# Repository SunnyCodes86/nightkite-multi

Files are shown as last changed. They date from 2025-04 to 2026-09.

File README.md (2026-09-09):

# Lenkdrachen LED Beleuchtung mit Bewegungsreaktion (Kite LED Lighting with Motion Response)

## Deutsch *(Version 3.0)*

Dieses Projekt realisiert eine dynamische LED-Beleuchtung für Lenkdrachen, die auf deren Bewegungen und Beschleunigungen reagiert. Die Farbe der LEDs wird durch den aktuellen Winkel des Drachens bestimmt, während die Geschwindigkeit der Animationsabläufe von der Bewegungsgeschwindigkeit des Drachens abhängt.

[Bedienungsanleitung](manual/manual_de.md)

### Features

* Helligkeit in 6 Stufen (95 → 255 in Schritten von 32) einstellbar – beeinflusst die Akkulaufzeit
* 27 Patterns/Animationen, davon fünf experimentelle V2-Audio-Sync-Patterns
* Autoplay zum automatischen Durchschalten durch aktivierte Pattern mit global einstellbarem Intervall
* Ladestandsanzeige über das LED-Band inkl. Ladefortschritt während USB-Verbindung
* Persistente Konfiguration in EEPROM: Pattern, Helligkeit, Strip-Länge, Motion-Smoothing, Sensor-Range, Boot-Kalibrierung, aktivierte/invertierte Pattern, Autoplay und MPU-Offsets
* USB-CLI für Status, Diagnose, Timing und Kalibrierung

### Verwendete Technologien und Komponenten

* **Mikrocontroller:** [Pimoroni Pico Lipo](https://shop.pimoroni.com) **(mit integriertem Akku-Management)**
* **Akku:** 500mAh LiPo Akku
* **Gyroskop/Beschleunigungsmesser:** [MPU6050 Modul](https://www.reichelt.de/de/de/shop/produkt/entwicklerboards_-_beschleunigung_gyroskop_3-achsen_mpu-6050-253987)
* **LED-Strip:** Zwei WS2812B Fairyight LED-Stränge mit je 25 Pixeln (50 Pixel gesamt)
* **Programmiersprache:** C++
* **Entwicklungsumgebung (optional):** [PlatformIO](https://platformio.org/) (für eigene Anpassungen)
* **Gewicht:** ca. 60 Gramm (Controller mit Gehäuse ca. 30 Gramm, LED-Strip ca. 30 Gramm)

### Hardware

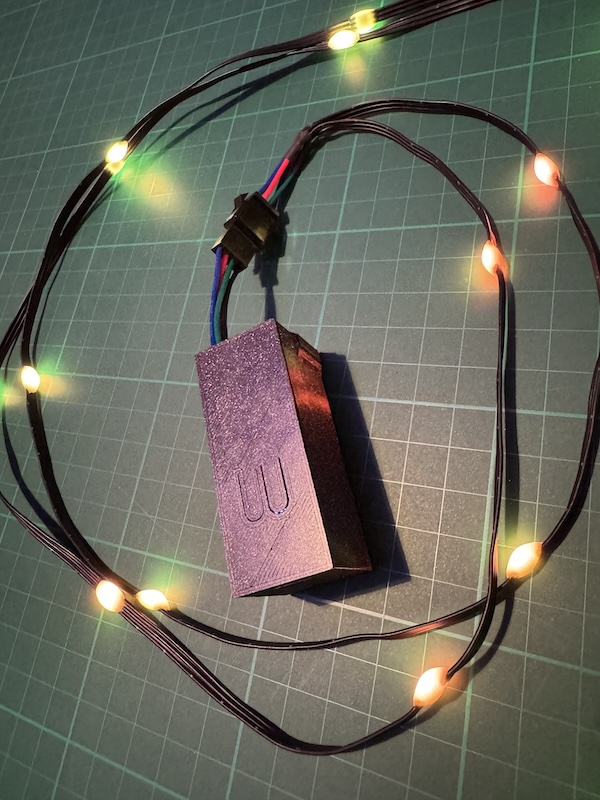
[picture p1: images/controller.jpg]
Bild des Controllers


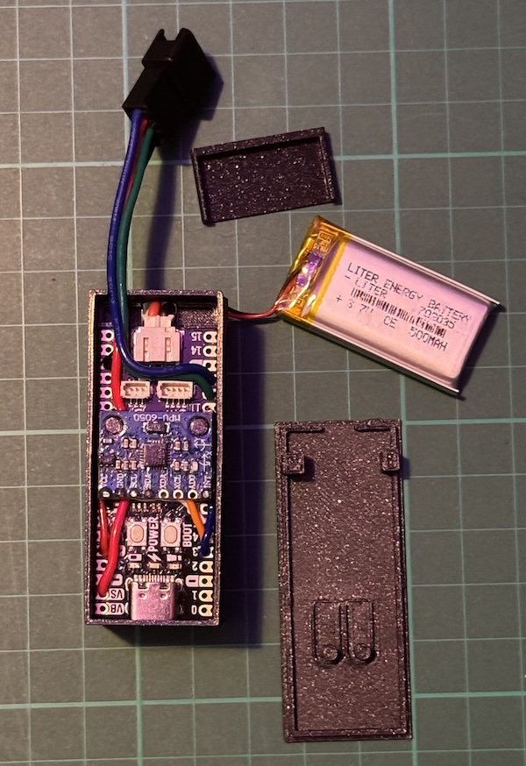
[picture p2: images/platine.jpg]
Bild der Platine


#### 3D-Druck Gehäuse

Für dieses Projekt steht ein Gehäuse zur Verfügung, das mit einem 3D-Drucker gefertigt werden kann. Die Dateien für den 3D-Druck (im 3MF- und STEP-Format) sowie eine Vorschau des Gehäuses befinden sich im Verzeichnis `case/` dieses Repositorys.

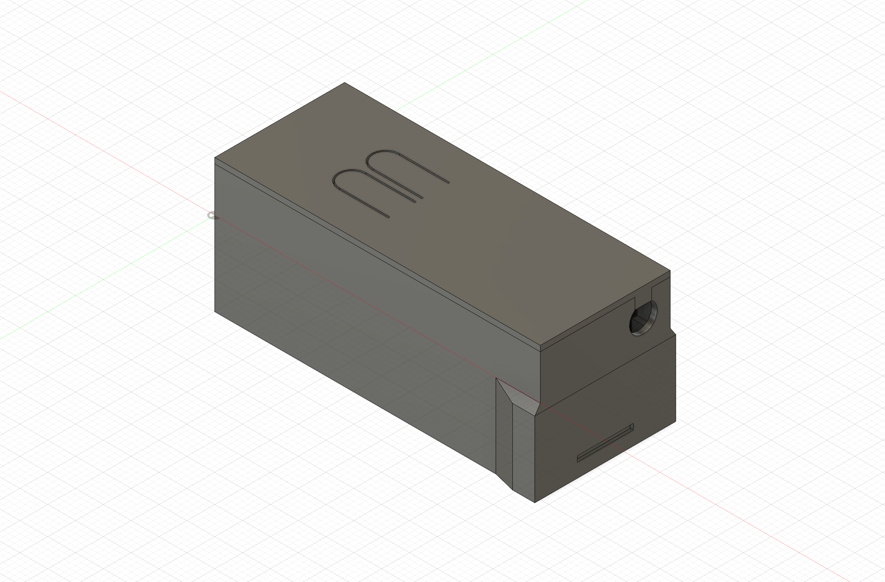
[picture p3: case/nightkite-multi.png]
Vorschau des Gehäuses


#### Verdrahtung

Die folgende Tabelle zeigt die Verbindungen zwischen dem Pimoroni Pico Lipo, dem LED-Strip und dem MPU6050:

| Komponente | Pin am Mikrocontroller |
| --- | --- |
| LED Strip + | VS (VSYS) |
| LED Strip - | GND |
| LED Strip 1 DIN | GP12 |
| LED Strip 2 DIN | GP13 |
| MPU6050 VCC | 3V3\_OUT |
| MPU6050 GND | GND |
| MPU6050 INT | GP3 |
| MPU6050 SDA | GP4 |
| MPU6050 SCL | GP5 |

### Stromversorgung und Laufzeit

Das System wird über einen integrierten 500mAh LiPo Akku betrieben. Der Pimoroni Pico Lipo verfügt über ein integriertes Akku-Management, das ein sicheres Laden und Entladen des Akkus gewährleistet.

**Aufladen:** Das Aufladen erfolgt bequem über den USB-C Anschluss am Mikrocontroller. Während des Ladevorgangs zeigt das LED-Band den Ladefortschritt als Prozent-Balken, eine rote LED blinkt zur Bestätigung.

**Laufzeit:** Die Akkulaufzeit beträgt, abhängig von der gewählten LED-Animation und der Helligkeit, zwischen 1 und 2,5 Stunden. Nach dem Abziehen vom USB springt das System automatisch zurück zum zuletzt aktiven Muster.

**Akkuwarnungen:** Die Firmware berechnet den Ladezustand über eine NightKite-spezifische LiPo-SoC-Kurve. Die Anzeige nutzt fünf Balken ab 80%, vier ab 60%, drei ab 40%, zwei ab 20%, einen gelben Balken ab 8% und unter 8% einen rot blinkenden Warnbalken. Unter 3.40 V wird nach ca. 15 s `LOW_WARNING` aktiv, unter 3.30 V nach ca. 10 s `CRITICAL` und die Helligkeit wird nur zur Laufzeit auf `MIN_BRIGHTNESS` begrenzt. Unter 3.20 V folgt nach ca. 15 s `SOFT_CUTOFF`: Die LEDs werden schwarz geschaltet, die Konfiguration wird defensiv gespeichert und Pattern-/Wireless-Aktivitaet stoppt. Unter ca. 3.08 V wird sofort `EMERGENCY_CUTOFF` aktiv. USB-Betrieb bzw. Laden loest diese Cutoffs nicht aus.

### Bedienung

Der Controller verfügt über zwei Tasten:

* **Linker Button:** Schaltet den Controller ein und aus.
* **Rechter Button:** Hat mehrere Funktionen:
    * **Doppelklick (2x kurz hintereinander):** Schaltet im normalen Betrieb zyklisch durch die aktivierten Animationsmuster.
    * **Kurz drücken (Shortpress):** Nur in der Akkuanzeige. Schaltet durch die 6 Helligkeitsstufen (95 → 127 → 159 → 191 → 223 → 255 → 95).
    * **Gedrückt halten (Longpress):** Öffnet die Akkuanzeige. Bis zu fünf LEDs dienen als Balkenanzeige; auf dem zweiten Strip blinkt eine blaue Markierung, gelbe LEDs zeigen die Helligkeitsstufe, und zwei weitere Status-LEDs zeigen Autoplay (`grün/grün` = an, `rot/rot` = aus).
    * **Doppelklick in der Akkuanzeige:** Schaltet Autoplay global ein oder aus.

**Initialisierung & Speicherfunktion:** Nach dem Einschalten lädt der Controller die gespeicherte Konfiguration und führt standardmäßig eine kurze MPU6050-Quick-Kalibrierung durch. Während dieser Phase (einige Sekunden) sollte der Controller ruhig gehalten werden. Die Boot-Kalibrierung kann über die CLI deaktiviert werden. Sobald die Initialisierung abgeschlossen ist, schalten sich die LEDs ein. Die zuletzt gespeicherten Werte werden automatisch geladen.

### Einfache Installation über .UF2-Datei

Für eine schnelle Inbetriebnahme kann eine fertig kompilierte `.uf2`-Datei verwendet werden. Gehe dazu wie folgt vor:

1.  **Boot-Modus aktivieren:** Halte den **rechten Knopf** auf dem Pimoroni Pico Lipo gedrückt, während du ihn über USB mit deinem Computer verbindest. Dadurch versetzt du den Mikrocontroller in den Boot-Modus.

2.  **Laufwerk erkennen:** Dein Computer sollte nun ein neues Laufwerk mit dem Namen `RPI-RP2` oder ähnlich anzeigen.

3.  **`.uf2`-Datei kopieren:** Lade die Datei `firmware.uf2` aus dem Release-Bereich dieses Repositorys herunter und ziehe sie per Drag & Drop auf das erkannte `RPI-RP2`-Laufwerk.

4.  **Automatischer Neustart:** Sobald die Datei kopiert wurde, wird der Pico automatisch neu gestartet und die LED-Beleuchtung sollte aktiv sein.

### Einrichtung und Start (für Entwickler und eigene Anpassungen)

Wenn du die Software selbst kompilieren oder Anpassungen vornehmen möchtest, sind folgende Schritte notwendig:

1.  **Installation von PlatformIO:** Stelle sicher, dass PlatformIO auf deinem System installiert ist. Eine detaillierte Anleitung findest du auf der [PlatformIO Webseite](https://platformio.org/install).

2.  **Klonen des Repositorys:** Klone dieses GitHub-Repository auf deinen lokalen Rechner.
    ```bash
    git clone [https://github.com/SunnyCodes86/nightkite-multi.git](https://github.com/SunnyCodes86/nightkite-multi.git)
    cd nightkite-multi
    ```

3.  **Konfiguration in `platformio.ini` (optional):** Überprüfe die `platformio.ini`-Datei im Projektverzeichnis. Hier sind die Umgebungsbedingungen für den Pimoroni Pico Lipo und die benötigten Bibliotheken definiert. Passe diese Datei bei Bedarf an deine spezifischen Bedürfnisse an.

4.  **Bibliotheken installieren:** PlatformIO sollte die benötigten Bibliotheken automatisch herunterladen und installieren, wenn du das Projekt kompilierst. Stelle sicher, dass in deiner `platformio.ini` die notwendigen Bibliotheken unter `lib_deps` aufgeführt sind.

5.  **Kompilieren und Hochladen:** Verbinde deinen Pimoroni Pico Lipo über USB mit deinem Computer. Nutze dann PlatformIO, um das Projekt zu kompilieren und auf den Mikrocontroller hochzuladen. Dies kann in der PlatformIO IDE oder über die Kommandozeile erfolgen:
    ```bash
    pio run -t upload
    ```

6.  **Los geht's!** Sobald die Software hochgeladen ist (entweder über `.uf2` oder PlatformIO) und die Hardware korrekt verbunden ist, sollte die LED-Beleuchtung deines Lenkdrachens auf dessen Bewegungen reagieren.

### USB-CLI

Sobald eine aktive serielle USB-Verbindung besteht, meldet sich die CLI mit:

```text
[NightKite CLI] USB connected. Type 'help'.
nk>
```

Verfügbare Kommandos:

```text
help
show
get <pattern|brightness|strip_length|smoothing|accel_range|gyro_range|boot_calibration>
get <pattern|brightness|strip_length|smoothing|accel_range|gyro_range|boot_calibration|autoplay|autoplay_interval|enabled_patterns|inverted_patterns>
set pattern <1..27>
set brightness <95|127|159|191|223|255>
set strip_length <10..35>
set smoothing <1..512>
set accel_range <2|4|8|16>
set gyro_range <250|500|1000|2000>
set boot_calibration <off|quick>
set autoplay <on|off>
set autoplay_interval <1..300>
patterns
enable_pattern <1..27[,id...]>
disable_pattern <1..27[,id...]>
invert_pattern <1..27[,id...]>
normal_pattern <1..27[,id...]>
battery
sensor
timing [reset]
offsets
calibrate quick
calibrate precise
save
load
defaults
reboot
restart
```

Hinweise:

* Daten-/Konfigurationskommandos antworten konsistent mit `OK ...` oder `ERR ...`, zum Beispiel `OK pattern=1`.
* `show` liefert alle relevanten Konfigurationswerte als kompakte `key=value`-Zeile.
* `show` enthält auch `autoplay`, `autoplay_interval`, `enabled_patterns` und `inverted_patterns`.
* `patterns` zeigt alle Pattern mit Status `on` oder `off`.
* `set pattern` schaltet das aktive Muster sofort um.
* `set pattern` darf auch deaktivierte Pattern direkt anwählen.
* Ein manueller Patternwechsel lässt Autoplay aktiv, setzt aber den Autoplay-Timer zurück.
* `set brightness` wirkt sofort.
* `set strip_length` wirkt sofort auf beide Strips.
* `enable_pattern` und `disable_pattern` steuern, welche Pattern per Doppelklick durchgeschaltet werden.
* Beide Befehle akzeptieren auch mehrere Pattern gleichzeitig als kommagetrennte Liste, z. B. `disable_pattern 3,5,7`.
* `invert_pattern` und `normal_pattern` steuern die Laufrichtung pro Pattern und speichern diese Einstellung persistent.
* Es muss immer mindestens ein Pattern aktiv bleiben.
* Autoplay verwendet nur aktivierte Pattern und kann persistent gespeichert werden.
* `smoothing`, `accel_range`, `gyro_range` und `boot_calibration` werden persistent gespeichert, greifen aber erst nach einem Neustart.
* `battery` zeigt ADC-Rohwert, geglaettete Spannung, `battery_percent`, `battery_state` sowie USB-/Serial-Status.
* `sensor` zeigt MPU-/DMP-Status und die konfigurierten bzw. aktiven Sensor-Ranges.
* `timing` zeigt `FastLED`-FPS, Loop-/Work-Zeiten, Frame-Budget und Samples in Mikrosekunden.
* `timing reset` setzt die Timing-Statistik (`avg`, `max`, `samples`) zurück, damit Pattern oder Änderungen direkt vergleichbar sind.
* `offsets` zeigt die aktuell verwendeten MPU-Offsets.
* `calibrate quick` führt die bisherige schnelle Kalibrierung aus und speichert die Offsets.
* `calibrate precise` nutzt den langsameren `IMU_Zero`-basierten Kalibrierpfad und speichert die Offsets.
* `calibrate quick` und `calibrate precise` starten mit `OK calibrate_started=1 ...` und enden mit `OK calibrate_finished=1 ...` plus finaler Offset-Zeile.
* `defaults` lädt nur Standardwerte in den Arbeitsspeicher. Für persistente Speicherung ist danach `save` nötig.
* Persistente Werte sind Device-Name, Pattern, Helligkeit, Strip-Laenge, Smoothing, Sensor-Ranges, Boot-Kalibrierung, Autoplay-/PlayMode-/BootMode-Einstellungen, Pattern-Masks, Sync- und Wireless-Einstellungen. Laufzeitdiagnosen wie Beacon-/Scan-Zaehler, `radio_mode`, `sync_locked`, Drift-/Phasenwerte, Battery-/USB-/BLE-Connection-Status und Timing-Counter werden bewusst nicht gespeichert.
* Live-Aenderungen wirken sofort. `save` speichert sie direkt persistent; der bestehende defensive Auto-Save kann geaenderte Werte spaeter ebenfalls sichern, sofern kein lokales Sync-Timing aktiv ist.

### Firmware 4.0 Alpha / NK4-Protokoll

Firmware `4.0.0-alpha.1` bereitet eine transportneutrale Kommando-Grundlage vor. Die bestehende USB-CLI bleibt der Human-/Legacy-Modus und damit der Fallback fuer Service, Diagnose und Kalibrierung. Zusaetzlich kann USB in einen maschinenlesbaren NK4-Modus wechseln:

```text
protocol machine
```

Danach antwortet die Firmware ohne Banner und Prompt nur noch mit NK4-Zeilen. NK4-Kommandos sind zeilenbasiert:

```text
NK4 seq=1 cmd=hello client=nightkite-link proto_min=4 proto_max=4
NK4 seq=2 cmd=info
NK4 seq=3 cmd=caps
NK4 seq=4 cmd=status
NK4 seq=10 cmd=get section=sync
NK4 seq=11 cmd=get section=wireless
NK4 seq=12 cmd=get section=play
NK4 seq=13 cmd=get section=patterns
NK4 seq=14 cmd=get section=config
NK4 seq=20 cmd=set name=NK-Left
NK4 seq=21 cmd=set pattern=8 brightness=159
NK4 seq=22 cmd=set sync_enabled=1 sync_group=1 sync_role=master
NK4 seq=23 cmd=set wireless_profile=long_range
NK4 seq=24 cmd=set play_mode=sync
NK4 seq=25 cmd=set strip_length=25 smoothing=100
NK4 seq=26 cmd=set enabled_mask=0x07FFFFFF inverted_mask=0x00000000
NK4 seq=30 cmd=save
NK4 seq=40 cmd=patterns
NK4 seq=41 cmd=battery
NK4 seq=42 cmd=sensor
NK4 seq=43 cmd=timing
NK4 seq=44 cmd=offsets
NK4 seq=45 cmd=calibrate mode=quick
NK4 seq=46 cmd=calibrate mode=precise
NK4 seq=50 cmd=sync_arm group=1 pattern=8 brightness=159 start_in=750 phase=0
NK4 seq=52 cmd=sync_status
NK4 seq=51 cmd=sync_cancel
NK4 seq=60 cmd=test indicator=play_modes
```

Antworten verwenden das Format `NK4 seq=<id> ok ...` oder `NK4 seq=<id> err code=<code> msg=<short_message>`. Schutzkommandos brauchen eine Bestaetigung, z. B. `NK4 seq=70 cmd=defaults confirm=1` und `NK4 seq=71 cmd=reboot confirm=1`.

NK4-Kalibrierung ist eine USB-Wartungsfunktion. Sie antwortet nach Abschluss einmal mit derselben Sequenz und den gespeicherten Offsets; `precise` kann mehrere Minuten dauern. Bei einer aktiven BLE-GATT-Verbindung wird `cmd=calibrate` mit `unsupported usb_only` abgewiesen, damit der lange blockierende Kalibrierpfad den Funktransport nicht festhält.

Die 4.0-Config erweitert die bestehende EEPROM-Konfiguration ohne die alten Adressen zu verschieben. Neu vorbereitet sind `device_uid`, `device_name`, `play_mode`, `boot_mode`, Sync-Einstellungen, Wireless-Einstellungen sowie kompakte Pattern-Masks. Beim ersten Start mit alter Config wird eine persistente UID erzeugt, daraus ein `short_id` abgeleitet und der Default-Name `NK-<short_id>` gesetzt. Die UID ist nicht per User-Kommando ueberschreibbar.

PlayMode ist jetzt als Steuerlogik mit `manual`, `autoplay` und `sync` angebunden. `manual` bleibt lokal auf dem aktuellen Pattern, `autoplay` nutzt das bestehende Autoplay-Verhalten, und `sync` bleibt lokal lauffaehig, auch wenn noch kein Funkmodul aktiv ist. Im Sync-Master-Modus kann `autoplay_enabled=1` genutzt werden: der Master wechselt dann automatisch durch die aktivierten Patterns und Follower uebernehmen Pattern und Helligkeit ueber die Sync-Beacons. Sync-Follower fuehren im Sync-Modus kein eigenes Autoplay aus, auch wenn `autoplay_enabled=1` gespeichert ist. Im Battery-View schaltet der vorhandene Mode-Button-Zyklus defensiv `manual -> autoplay -> sync -> manual`; der normale Pattern-Wechsel ausserhalb des Battery-Views bleibt erhalten. Die Status-Farben sind blau fuer manual, gruen fuer autoplay, cyan fuer sync follower, magenta fuer sync master und rot blinkend fuer sync error/no master. `NK4 cmd=test indicator=play_modes` zeigt diese Farben nacheinander auf dem Strip.

`SyncEngine` und `PatternClock` verwalten in diesem Alpha-Schritt lokale Sync-Zustaende, geplante lokale Starts, Pattern, Helligkeit, Phase und Pattern-Zeit. `sync_arm`, `sync_status` und `sync_cancel` funktionieren lokal und loesen keine direkten EEPROM-Schreibvorgaenge aus; automatische Config-Saves werden waehrend aktivem lokalen Sync-Timing zurueckgestellt. Das experimentelle Sync-Beacon-V1-Modell uebertraegt Group, Flags, Sequenz, Pattern, Helligkeit, Phase, Beat und CRC. Follower akzeptieren zusaetzlich V2-Beacons mit Energy, Bass, Mid, Treble und Confidence. Die V2-Flags sind `BEAT=0x01`, `SIGNAL_VALID=0x02` und `BEAT_LOCKED=0x04`; Paketgroesse und CRC-Layout bleiben unveraendert. Die V2-Audiodaten werden als kurzlebiger Runtime-Status gespeichert und steuern die Patterns 23 bis 27; die Audioanalyse selbst findet im Cardputer statt. Es werden keine LED-Frames ueber Funk gestreamt.

Sync-Timing ist ueber NK4 diagnostizierbar. `sync_status` und `get section=sync` melden u. a. `last_beacon_pattern`, `last_beacon_seq`, `last_applied_seq`, `phase_ms`, `beacon_phase_ms`, `sync_apply_count`, `sync_apply_skipped`, `sync_apply_reason`, `pattern_change_count`, `last_pattern_change_latency_ms`, `sync_ready_pattern` und `partial_sync_pattern`. `patterns` und `get section=patterns` enthalten zusaetzlich `sync_ready_mask`, `partial_sync_mask` und `local_reactive_mask`. Pattern 1 `rainbow` ist aktuell der reine sync-ready Kandidat. Die Patterns 4 `runner_fixed`, 7 `heartbeat`, 8 `ping_pong`, 10 `breath_storm`, 15 `palette_beat_motion`, 16 `pacifica_kite`, 19 `noise_ring`, 20 `pride_yaw` sowie 23 bis 27 nutzen synchronisierte Zeit- oder Audiowerte, behalten aber lokale Motion-/Yaw-/Farbanteile und sind deshalb partial-sync. Die Patterns 2, 3, 5, 6, 9, 11, 12, 13, 14, 17, 18, 21 und 22 bleiben local-reactive/TODO; sie folgen Pattern und Helligkeit, duerfen visuell aber pro Controller unterschiedlich reagieren.

Die neuen Audio-Patterns sind `audio_pulse_angle_color` (23), `audio_spectrum_ribbon` (24), `audio_beat_ripples` (25), `audio_band_comets` (26) und `audio_beat_mosaic` (27). Energy und Frequenzbaender bestimmen Helligkeit, Form und Akzente; Beat, BeatMs und Phase halten die Bewegung synchron. Yaw, Pitch oder lokale Bewegung beeinflussen weiterhin die Farbe. Bei V1, `SIGNAL_VALID=0` oder wenn laenger als 500 ms kein neues gueltiges V2-Audioframe empfangen wurde, werden alle fuenf Patterns schwarz und ihre Audiohistorie wird zurueckgesetzt. Bei gueltigem Signal ohne `BEAT_LOCKED` bleiben Energy und Baender aktiv, Phase und synthetischer Beat-Puls aber null. Es gibt keinen lokalen oder synthetischen Audiofallback. Werkseinstellungen aktivieren alle 27 Patterns. Config-Version 401 aktiviert die neuen IDs einmalig auch in aelteren gespeicherten Pattern-Masks; Config-Version 402 ergaenzt den persistenten Show-Control-Empfang, der bei Migration aus 400/401 standardmaessig aus bleibt.

Zusaetzlich zu den Basis-Kommandos sind maschinenlesbare Diagnose- und Config-Kommandos verfuegbar: `battery`, `sensor`, `timing`, `offsets`, `get section=config`, `set strip_length`, `set smoothing`, `set accel_range`, `set gyro_range`, `set boot_calibration`, `set boot_mode`, `set enabled_mask`, `set inverted_mask`, `enable_pattern`, `disable_pattern`, `invert_pattern` und `normal_pattern`. Ungueltige Werte werden mit standardisierten `NK4 ... err code=...` Antworten abgewiesen.

RM2/BLE-Pins und Build-Flags sind vorbereitet (`NIGHTKITE_RM2`, `NIGHTKITE_BLE`), bleiben in den Standard-Builds aber deaktiviert. WLAN wird nicht als Firmware-Feature verwendet: kein `WiFi.begin`, kein Scan, kein Webserver.

Aktuelle RM2-Verkabelung am Pimoroni Pico LiPo 2:

| Pico LiPo 2 | RM2 Breakout |
| --- | --- |
| GP17 | BL_ON/WL_ON |
| GP18 | CS |
| GP19 | CLK |
| GP20 | DAT/WL_WAKE |
| 3V3 | 3V3 |
| GND | GND |

Das RM2 Breakout ist hart an die Aussenpads geloetet und nicht ueber den SP/CE-JST-Stecker verbunden. BL_ON und WL_ON sind auf dem Breakout hardwareseitig gebrueckt und haengen gemeinsam an GP17. GPIO0, GPIO1 und GPIO2 des RM2 Breakouts sind nicht verbunden.

Experimenteller BLE/RM2-Build:

```bash
platformio run -e pico2350_rm2_ble
platformio run -e pico2350_rm2_ble -t upload
```

Dieses Environment aktiviert `NIGHTKITE_BLE=1`, `NIGHTKITE_RM2=1`, den Arduino-Pico-Bluetooth-Stack und die dynamische CYW43/RM2-Pinbelegung fuer GP17-GP20. Der Build startet BLE-Advertising mit einem kompakten Namen wie `NK-<short_id>`, stellt experimentell einen NK4-over-BLE-GATT-Transport bereit und enthaelt einen ersten autonomen Sync-Beacon-Radio. WLAN wird nicht verwendet.

NightKite BLE-GATT:

```text
Service UUID: 4e4b4000-6e69-6768-746b-000000000001
RX UUID:      4e4b4000-6e69-6768-746b-000000000002  write/write-without-response
TX UUID:      4e4b4000-6e69-6768-746b-000000000003  notify
```

Der BLE-Transport nutzt dieselben zeilenbasierten NK4-Kommandos wie USB. Newline `\n` beendet ein Kommando; Antworten kommen ueber TX Notify in kleinen Chunks zurueck. Der Status ist ueber USB/NK4 sichtbar:

```text
NK4 seq=4 cmd=get section=wireless
NK4 seq=5 cmd=ble_status
```

Wichtige Felder sind `ble_supported`, `ble_enabled`, `rm2_enabled`, `rm2_pins`, `ble_initialized`, `ble_advertising`, `ble_connected`, `ble_gatt`, `ble_rx`, `ble_tx`, `ble_tx_queue`, `ble_tx_dropped`, `ble_notify_ready`, `ble_tx_active`, `ble_tx_offset`, `ble_tx_chunks_sent`, `ble_name`, `last_error` und `wifi=0`. Ein BLE-Scan mit nRF Connect oder einem Smartphone sollte im Erfolgsfall `NK-<short_id>` anzeigen.

Experimenteller Sync-Beacon-Radio:

- `standalone`: kein Beacon-Radio aktiv.
- `master`: wenn `play_mode=sync`, `sync_enabled=1` und `wireless_enabled=1`, sendet der Controller kleine nicht-connectable BLE-Advertising-Pakete mit Herstellerdaten-Payload. Die Beacon-Rate richtet sich nach `wireless_profile`: `long_range` ca. 5 Hz, `balanced` ca. 10 Hz, `fast_sync` ca. 20 Hz.
- `follower`: wenn `play_mode=sync`, `sync_enabled=1` und `wireless_enabled=1`, scannt der Controller nach gueltigen NightKite-Beacons derselben `sync_group`. Beacons mit falscher Gruppe oder CRC werden ignoriert und gezaehlt.

Bei Beacon-Verlust laesst `sync_loss_behavior=continue_local` das letzte Pattern lokal weiterlaufen, `fallback_autoplay` wechselt in lokales Autoplay und `warning_only` behaelt das Pattern mit roter Loss-Warnung in der Statusanzeige bei. `get section=sync` meldet dazu `sync_loss_count`, `last_sync_loss_ms` und `last_sync_loss_action`. `sync_pattern` bezeichnet das zuletzt gueltige Sync-Ziel, waehrend `local_pattern` das tatsaechlich gerenderte Pattern zeigt.

Der Controller-Master sendet weiterhin unveraendert V1. Der Follower-Decoder akzeptiert V1 und V2; beide Versionen speisen dieselben bestehenden Sync-Basisdaten ein. V2 ist 22 Byte gross, hat 24 Byte Manufacturer Data inklusive Company ID und passt damit in ein 29-Byte-Legacy-Advertising-Paket. Die Manufacturer-Data-Signatur beginnt mit `FFFF4E4B02...`. Ein frisches V2 setzt `audio_valid` nur mit `SIGNAL_VALID`; alte Sender ohne dieses Bit gelten konservativ als ohne gueltiges Audio. Nur `BEAT_LOCKED` aktiviert BeatMs und Phase. Nach 500 ms ohne neues gueltiges V2-Audioframe wird `audio_valid=0`; identische wiederholte V2-Sequenzen verlaengern die Audio-Freshness nicht. Der allgemeine Controller-Sync-Verlust bleibt davon getrennt bei 1500 ms.

Hardwaretest der Audio-Patterns:

1. Controller mit dem BLE/RM2-Build als Follower in dieselbe Sync-Gruppe wie den Cardputer setzen.
2. Bei einer bereits gespeicherten alten Pattern-Maske einmal `enable_pattern 23,24,25,26,27` und `save` ausfuehren.
3. Auf dem Cardputer `V2 Mic Full` starten und nacheinander Pattern 23 bis 27 senden.
4. Auf dem Controller pruefen:

```text
NK4 seq=20 cmd=audio_sync_status
NK4 seq=10 cmd=get section=sync
```

Erwartet werden bei echtem Signal `signal_valid=1`, `audio_valid=1`, `last_beacon_version=2`, steigendes `scan_decode_v2`, `sync_locked=1`, `scan_crc_fail=0` und sichtbare Reaktionen auf Pegel und Baender. Beatphase ist erst bei `beat_locked=1` aktiv. Bei geschlossenem Gate bleiben 23 bis 27 trotz frischer V2-Pakete schwarz. Der Test erfordert einen Cardputer/NightKite-Link-Build mit V2-Audio-Sync-Unterstuetzung.

GATT/NK4 bleibt der Konfigurations- und Diagnosepfad. Der Beacon-Radio nutzt keine GATT-Kommandos fuer Echtzeit-Sync und sendet keine Acknowledgements. Wenn ein BLE-GATT-Client verbunden ist, hat der Config/GATT-Modus Vorrang und der Beacon-Radio meldet `radio_mode=gatt`; USB bleibt immer als Fallback verfuegbar. Im Beacon-Master-Modus kontrolliert der Sync-Radio das Advertising und das normale `NK-...`-GATT-Advertising wird unterdrueckt. Ein BLE-Scanner muss den Controller in diesem Modus nicht als normales GATT-Geraet anzeigen; sichtbar sein sollte ein namenloses bzw. non-connectable Advertising mit Manufacturer Data `FFFF4E4B01...` oder als Rohpaket etwa `02010614FFFFFF4E4B01...`.

Die bestehenden Radio-Diagnosefelder bleiben in `NK4 cmd=get section=sync`, `NK4 cmd=sync_status`, `NK4 cmd=sync_radio_status` und `NK4 cmd=get section=wireless` sichtbar. Die kurze, auch fuer BLE-GATT geeignete Abfrage `NK4 seq=<n> cmd=audio_sync_status` liefert `audio_sync`, `audio_valid`, `signal_valid`, `beat_locked`, `last_beacon_version`, `scan_decode_v1`, `scan_decode_v2`, `audio_seq`, `audio_age_ms`, `audio_beat`, `audio_energy`, `audio_bass`, `audio_mid`, `audio_treble`, `audio_confidence`, `audio_phase_ms`, `audio_beat_ms` und `audio_timeout_ms`.

Manueller nRF-Connect-Test:

1. Nach `NK-<short_id>` scannen und verbinden.
2. TX Characteristic Notifications aktivieren.
3. In die RX Characteristic schreiben:

```text
NK4 seq=10 cmd=hello client=nrf proto_min=4 proto_max=4\n
```

4. Auf TX Notify eine Antwort wie `NK4 seq=10 ok ...` erwarten.
5. Danach weitere Kommandos testen:

```text
NK4 seq=11 cmd=info\n
NK4 seq=12 cmd=status\n
NK4 seq=13 cmd=get section=wireless\n
```

### Hinweise zur Kalibrierung

Es gibt zwei Kalibrierpfade:

* **Quick Calibration:** Standard beim Boot, wenige Sekunden, ausreichend für den Alltag.
* **Precise Calibration:** Nur manuell per CLI, dauert deutlich länger und sollte nur bei ruhigem, waagerecht abgelegtem Gerät durchgeführt werden.

Empfehlung:

1. Gerät vor einer präzisen Kalibrierung 5-10 Minuten thermisch stabilisieren.
2. Controller absolut ruhig und waagerecht platzieren.
3. `calibrate precise` ausführen.
4. Danach optional `set boot_calibration off` und `save`, wenn künftig nur mit gespeicherten Offsets gestartet werden soll.

### Lizenz

Dieses Projekt ist unter der [MIT Lizenz](LICENSE.txt) lizenziert.

---

## English *(Version 3.0)*

This project implements dynamic LED lighting for kites that reacts to their movements and accelerations. The color of the LEDs is determined by the current angle of the kite, while the speed of the animation sequences depends on the kite's speed of motion.

[User Manual](manual/manual_en.md)

### Features

* Six brightness levels (95 → 255 in steps of 32) impact the battery runtime
* 27 patterns/animations, including five experimental V2 audio-sync patterns
* Autoplay for automatic cycling through enabled patterns with a configurable global interval
* Battery level indicator on the LED strip including charging progress while on USB power
* Persistent EEPROM configuration for pattern, brightness, strip length, motion smoothing, sensor ranges, boot calibration, enabled/inverted patterns, autoplay, and MPU offsets
* USB CLI for configuration, diagnostics, timing, and calibration

### Used Technologies and Components

* **Microcontroller:** [Pimoroni Pico Lipo](https://shop.pimoroni.com) **(with integrated battery management)**
* **Battery:** 500mAh LiPo battery
* **Gyroscope/Accelerometer:** [MPU6050 Module](https://www.reichelt.de/de/en/shop/product/developer-boards-acceleration-gyroscope-3-axes-mpu-6050-253987)
* **LED Strips:** Two WS2812B Fairyight strings with 25 pixels each (50 pixels total)
* **Programming Language:** C++
* **Development Environment (optional):** [PlatformIO](https://platformio.org/) (for own adaptations)
* **Weight:** approx. 60 grams (controller with case approx. 30 grams, LED strip approx. 30 grams)

### Hardware

Controller Image

Board Image

#### 3D-Printed Case

An optional case for this project is available and can be manufactured with a 3D printer. The files for 3D printing (in 3MF and STEP format) as well as a preview of the case can be found in the `case/` directory of this repository.

Case Preview

#### Wiring

The following table shows the connections between the Pimoroni Pico Lipo, the LED strip, and the MPU6050:

| Component | Pin on Microcontroller |
| --- | --- |
| LED Strip + | VS (VSYS) |
| LED Strip - | GND |
| LED Strip 1 DIN | GP12 |
| LED Strip 2 DIN | GP13 |
| MPU6050 VCC | 3V3\_OUT |
| MPU6050 GND | GND |
| MPU6050 INT | GP3 |
| MPU6050 SDA | GP4 |
| MPU6050 SCL | GP5 |

### Power Supply and Runtime

The system is powered by an integrated 500mAh LiPo battery. The Pimoroni Pico Lipo features integrated battery management, ensuring safe charging and discharging of the battery.

**Charging:** Charging is done via the USB-C port on the microcontroller. While charging, the LED strip displays a percentage-based progress bar and a red LED blinks to indicate active charging.

**Runtime:** Battery runtime is between 1 and 2.5 hours, depending on the selected LED animation and brightness. After unplugging USB power the controller automatically resumes the last active pattern.

**Battery warnings:** Firmware now estimates state of charge with a NightKite-specific LiPo SoC curve. The LED indicator shows five bars at 80% and above, four at 60%, three at 40%, two at 20%, one yellow bar at 8%, and a blinking red warning below 8%. Below 3.40 V for about 15 s the state becomes `LOW_WARNING`; below 3.30 V for about 10 s it becomes `CRITICAL` and runtime brightness is capped to `MIN_BRIGHTNESS` without overwriting the saved brightness. Below 3.20 V for about 15 s, `SOFT_CUTOFF` turns LEDs black, defensively saves the current configuration, and stops pattern/wireless activity. Below about 3.08 V, `EMERGENCY_CUTOFF` happens immediately. USB power or charging suppresses low-battery cutoffs.

### Operation

The controller has two buttons:

* **Left Button:** Turns the controller on and off.
* **Right Button:** Provides multiple functions:
    * **Double click (two quick presses):** In normal operation, cycles through the enabled animation patterns.
    * **Short press:** Only in battery display mode. Cycles through the six brightness levels (95 → 127 → 159 → 191 → 223 → 255 → 95).
    * **Long press:** Opens the battery display. Up to five LEDs form a bar indicator; on the second strip a blue marker LED blinks, yellow LEDs show brightness level, and two additional status LEDs show autoplay (`green/green` = on, `red/red` = off).
    * **Double click in battery display:** Toggles autoplay globally.

**Initialization & Persistence:** After power-on, the controller loads the stored configuration and by default performs a short MPU6050 quick calibration. Keep the controller still for a few seconds during this phase. Boot calibration can be disabled via the CLI. Once initialization is complete, the LEDs turn on and the stored configuration is restored automatically.

### Easy Installation via .UF2 File

For quick setup, a pre-compiled `.uf2` file can be used. Proceed as follows:

1.  **Activate Boot Mode:** Press and hold the **right button** on the Pimoroni Pico Lipo while connecting it to your computer via USB. This puts the microcontroller into boot mode.

2.  **Recognize Drive:** Your computer should now display a new drive named `RPI-RP2` or similar.

3.  **Copy `.uf2` File:** Download the `firmware.uf2` file from the release section of this repository and drag and drop it onto the recognized `RPI-RP2` drive.

4.  **Automatic Restart:** Once the file is copied, the Pico will restart automatically, and the LED lighting should be active.

### Setup and Start (for Developers and Own Adaptations)

If you want to compile the software yourself or make adjustments, the following steps are necessary:

1.  **Install PlatformIO:** Make sure PlatformIO is installed on your system. Detailed instructions can be found on the [PlatformIO website](https://platformio.org/install).

2.  **Clone the Repository:** Clone this GitHub repository to your local machine.
    ```bash
    git clone [https://github.com/SunnyCodes86/nightkite-multi.git](https://github.com/SunnyCodes86/nightkite-multi.git)
    cd nightkite-multi
    ```

3.  **Configuration in `platformio.ini` (optional):** Check the `platformio.ini` file in the project directory. Here, the environment settings for the Pimoroni Pico Lipo and the required libraries are defined. Adjust this file to your specific needs if necessary.

4.  **Install Libraries:** PlatformIO should automatically download and install the required libraries when you compile the project. Ensure that the necessary libraries are listed under `lib_deps` in your `platformio.ini`.

5.  **Compile and Upload:** Connect your Pimoroni Pico Lipo to your computer via USB. Then use PlatformIO to compile the project and upload it to the microcontroller. This can be done in the PlatformIO IDE or via the command line:
    ```bash
    pio run -t upload
    ```

6.  **Let's Go!** Once the software is uploaded (either via `.uf2` or PlatformIO) and the hardware is correctly connected, the LED lighting of your kite should react to its movements.

### USB CLI

As soon as an active USB serial connection exists, the CLI announces itself with:

```text
[NightKite CLI] USB connected. Type 'help'.
nk>
```

Available commands:

```text
help
show
get <pattern|brightness|strip_length|smoothing|accel_range|gyro_range|boot_calibration|autoplay|autoplay_interval|enabled_patterns|inverted_patterns>
set pattern <1..27>
set brightness <95|127|159|191|223|255>
set strip_length <10..35>
set smoothing <1..512>
set accel_range <2|4|8|16>
set gyro_range <250|500|1000|2000>
set boot_calibration <off|quick>
set autoplay <on|off>
set autoplay_interval <1..300>
patterns
enable_pattern <1..27[,id...]>
disable_pattern <1..27[,id...]>
invert_pattern <1..27[,id...]>
normal_pattern <1..27[,id...]>
battery
sensor
timing [reset]
offsets
calibrate quick
calibrate precise
save
load
defaults
reboot
restart
```

Notes:

* Data/config commands reply consistently with `OK ...` or `ERR ...`, for example `OK pattern=1`.
* `show` returns all relevant configuration values as a compact `key=value` line.
* `show` also includes `autoplay`, `autoplay_interval`, `enabled_patterns`, and `inverted_patterns`.
* `patterns` lists all patterns with `on` or `off` state.
* `set pattern` switches the active pattern immediately.
* `set pattern` can also select patterns that are currently disabled for button cycling.
* A manual pattern change keeps autoplay enabled, but resets the autoplay timer.
* `set brightness` takes effect immediately.
* `set strip_length` applies immediately to both strips.
* `enable_pattern` and `disable_pattern` control which patterns are included when cycling with the button.
* Both commands also accept multiple pattern IDs as a comma-separated list, for example `disable_pattern 3,5,7`.
* `invert_pattern` and `normal_pattern` control per-pattern animation direction and store that setting persistently.
* At least one pattern must always remain enabled.
* Autoplay uses only enabled patterns and can be stored persistently.
* `smoothing`, `accel_range`, `gyro_range`, and `boot_calibration` are stored persistently but only take effect after reboot.
* `battery` reports raw ADC value, smoothed voltage, `battery_percent`, `battery_state`, and USB/serial status.
* `sensor` reports MPU/DMP status and both configured and active sensor ranges.
* `timing` reports `FastLED` FPS, loop/work timings, frame budget, and sample count in microseconds.
* `timing reset` clears the timing statistics (`avg`, `max`, `samples`) so patterns or changes can be compared directly.
* `offsets` reports the currently active MPU offsets.
* `calibrate quick` runs the fast calibration path and saves the resulting offsets.
* `calibrate precise` runs the slower `IMU_Zero`-style calibration path and saves the resulting offsets.
* `calibrate quick` and `calibrate precise` start with `OK calibrate_started=1 ...` and finish with `OK calibrate_finished=1 ...` plus a final offsets line.
* In USB machine mode, use `NK4 seq=<id> cmd=calibrate mode=quick|precise`. NK4 returns one sequence-matched completion after saving; BLE GATT rejects this blocking maintenance operation with `unsupported usb_only`.
* `defaults` only loads factory defaults into working memory. Run `save` afterwards if you want to keep them permanently.
* Persistent values are device name, pattern, brightness, strip length, smoothing, sensor ranges, boot calibration, autoplay/play mode/boot mode settings, pattern masks, sync settings, and wireless settings. Runtime diagnostics such as beacon/scan counters, `radio_mode`, `sync_locked`, drift/phase values, battery/USB/BLE connection state, and timing counters are intentionally not stored.
* Live changes take effect immediately. `save` stores them persistently right away; the existing defensive auto-save may also persist changed values later when no local sync timing is active.

### Calibration Notes

Two calibration modes are available:

* **Quick Calibration:** Default during boot, takes only a few seconds, suitable for normal use.
* **Precise Calibration:** Manual CLI-only maintenance command, takes much longer and should only be run with the device lying still on a flat surface.

Recommended procedure:

1. Let the device thermally stabilize for 5-10 minutes before precise calibration.
2. Place the controller on a flat, level, motionless surface.
3. Run `calibrate precise`.
4. Optionally switch to stored offsets only via `set boot_calibration off` and `save`.

### License

This project is licensed under the [MIT License](LICENSE.txt).

---

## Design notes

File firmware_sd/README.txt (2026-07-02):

NightKite firmware bundle for NightKite Link SD card

Files:
- NK20_P2040.uf2   = firmware 2.0, Pico LiPo / RP2040
- NK30_P2040.uf2   = firmware 3.0, Pico LiPo / RP2040
- NK30_P2350.uf2   = firmware 3.0, Pico LiPo 2 / RP2350
- NK40D_P2040.uf2  = firmware 4.0-dev, Pico LiPo / RP2040
                      PlatformIO environment: pico2040
- NK40D_P2350.uf2  = firmware 4.0-dev, Pico LiPo 2 / RP2350, no RM2 radio
                      PlatformIO environment: pico2350
- NK40D_RM2BLE.uf2 = firmware 4.0-dev, Pico LiPo 2 / RP2350 with the wired
                      RM2 BLE breakout on GP17-GP20
                      PlatformIO environment: pico2350_rm2_ble

Sources:
- 2.0: git tag v2.0
- 3.0: git tag v3.0
- 4.0-dev: dev branch commit c155faa (Migrate enabled audio sync patterns)
           Runtime version: 4.0.0-alpha.1

The current 4.0-dev builds include 27 patterns, Sync Beacon V1 compatibility,
V2 Audio Sync beacon receive support, AudioSyncState diagnostics and timeout,
the audio-reactive patterns 23-27, and stabilized pattern/sync loss handling.
Config version 401 migrates older config-400 enabled-pattern masks once so
patterns 23-27 are enabled after updating; later saved choices remain intact.

NightKite Link lists every .uf2 file from /firmware and does not require these
exact filenames. In Firmware Update, select target RP2040 for NK20/NK30/NK40D
P2040 files. Select target RP2350 for NK30/NK40D P2350 and NK40D_RM2BLE files.
Use NK40D_RM2BLE only on the RP2350 controller with the wired RM2 breakout.

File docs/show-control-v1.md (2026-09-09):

# NightKite Multi: Show Control V1

Firmware-side contract for a subsequent NightKite Link / PC-gateway sender. No
sender, MIDI/OSC, Wi-Fi, extended advertisements or pixel streaming is implemented
here. Patterns remain IDs **1–27**. Show Control is a runtime output layer.

## Enable and radio ownership

Before flight, on the BLE/RM2 firmware:

```text
NK4 seq=1 cmd=set wireless_enabled=1
NK4 seq=2 cmd=show_control enabled=1
NK4 seq=3 cmd=save
NK4 seq=4 cmd=show_status
```

`show_control enabled=0|1` changes the receive preference immediately; the existing
`cmd=save` persists it together with `wireless_enabled`. Save before flight and
check `saved=1`. Without save, changes follow the ordinary unsaved-config semantics.
Repeating `enabled=1` preserves runtime state. `enabled=0` cancels the queue,
clock/dedupe history and output override. `show_status` works on every build;
enabling on non-BLE builds returns `unsupported / show_radio_unavailable`.
`get section=wireless` appends `show_control_enabled`. Standard `status` adds
`show_active`, `show_queue`; `caps` adds `show_control`. Existing fields and
`get section=show` (configuration) retain their meanings.

Config version **402** appends a 32-bit integer receive flag at EEPROM bytes
**188–191**, 0 disabled / 1 enabled. EEPROM size 224, magic, all earlier addresses
and meanings remain unchanged. Versions 400/401 migrate with show reception off,
ignoring formerly unused bytes; their wireless, identity and sync settings survive.
Only v400 receives the existing audio-pattern-mask migration. Invalid receive flags
normalize to off. Recovery uses the existing one-time config save path. Downgrading
to firmware that only understands v401 can reset extended settings through that
older firmware's existing unknown-version recovery; export settings before downgrade.

A reboot/brownout restores the **saved receive preference**, but never resumes a
show: overrides, clocks, queues, IDs, pending/front buffers and diagnostics start
empty. Config load/reset also clears execution state. No show event writes flash.
The sender must rebuild its pending image and re-establish show time after a
controller reboot; initial output follows normal saved local/sync configuration.

- Active autonomous master (`play_mode=sync`, `sync_enabled=1`, `sync_role=master`)
  owns V1 beacon TX. It does not receive Show Control, even when enabled.
- Active follower scans for the existing V1/V2 beacons. With show enabled it also
  processes Show V1 in that same scan, with no sender/master address binding.
- Otherwise show enabled + wireless enabled selects `radio_mode=show_receiver`:
  scan for Show V1 and group-matching Audio V2; keep local manual/autoplay runtime
  underneath. Plain V1/V2 pattern/brightness fields do not take control of a local
  controller. Use a follower when those fields should control the underlying state.
- Connected GATT retains priority. Scanning stops until disconnect. Already queued
  events can still execute; audio expires normally. Scanner modes suppress GATT
  advertising as the existing follower does. USB remains available for recovery.
- Disabling wireless, changing group, entering autonomous master operation or
  battery cutoff cancels show events and releases the override. Reboot clears the
  complete show session and loads the existing saved configuration.

This uses the existing passive scan parameters (60 ms interval / 30 ms window).
No simultaneous autonomous master-TX/show-RX time slicing is attempted. Preflight
configuration can use USB or GATT; neither is required during flight.

## Complete advertisement (31 bytes)

Legacy non-connectable advertising, company ID `0xFFFF` (existing experimental
NightKite ID). Offsets below are zero-based. All multibyte integers are **little
endian**, including the 24-bit target, event ID and CRC.

| Advertisement bytes | Meaning |
| --- | --- |
| 0–2 | `02 01 06`: Flags AD structure |
| 3–4 | `1B FF`: Manufacturer AD length 27 and type 0xFF |
| 5–6 | `FF FF`: company ID |
| 7–30 | 24-byte Show Control packet below |

| Packet offset | Size | Field |
| --- | --- | --- |
| 0–1 | 2 | Magic ASCII `NS` (`4E 53`), distinct from sync `NK` |
| 2 | 1 | Version `01` = SHOW_CONTROL_V1 |
| 3 | 1 | Bits 7–6 target kind; bits 5–0 command ID |
| 4–6 | 3 | Target value |
| 7–8 | 2 | Event ID, modulo 65536 |
| 9–12 | 4 | Sender monotonic show time in milliseconds, modulo 2^32 |
| 13–14 | 2 | Low 16 bits of absolute execution time on that same clock |
| 15–21 | 7 | Command parameters; unused bytes MUST be zero |
| 22–23 | 2 | CRC16-CCITT |

CRC: polynomial `0x1021`, initial value `0xFFFF`, no reflection, no final XOR.
Compute over **all 24 packet bytes with bytes 22–23 zeroed**; store result LE.
The AD framing/company ID are not covered. The payload length must equal 24;
unknown version, target kind, command, out-of-range parameters or nonzero reserved
parameters are rejected. Sync V1 (17 bytes) and V2 (22 bytes), their fields and
CRC-zeroing rules are unchanged. Their original codec is now isolated in
`src/protocol/SyncBeaconCodec.*` for host testing.

Independent example: SINGLE `ABC123`, event `0x1234`, sender time `0x12345678`,
execute at `0x12345A00`, segment image 42 / index 1 / start 15 / count 10 / blue:

```text
02 01 06 1B FF FF FF 4E 53 01 87 23 C1 AB 34 12 78 56 34 12 00 5A 2A 01 0F 0A 00 00 FF 73 85
```

## Targets

| Kind (bits 7–6) | Value | Match |
| --- | --- | --- |
| 0 ALL | Must be 0 | Every show-enabled receiver, independent of sync group |
| 1 GROUP | 1–255, upper two bytes zero | Existing configured `sync_group` |
| 2 SINGLE | 0–0xFFFFFF | Numeric hex value of existing six-character `short_id` |
| 3 | Reserved | Reject |

The short ID is the final six hex characters of the existing persistent device
UID (also advertised as `NK-xxxxxx`). It is a target, never a master identity.
Short-ID collisions are possible; check the fleet before using SINGLE targeting.
For A and C, send two SINGLE events with separate IDs and the **same absolute
execution time**. Use GROUP/ALL when applicable. Audio reception always uses the
configured sync group, even if the show command was targeted ALL or SINGLE.

## Clock, scheduling, retransmission

Reconstruct the absolute sender deadline as:

```text
delta = signed16(execute_low16 - low16(sender_ms))
execute32 = sender_ms + delta                  # modulo 2^32
```

Only `-250 <= delta <= 30000` ms is legal. Deadlines more than 30 s away must be
sent later. Do not encode a different 65536-ms epoch as if it were this one.
All time and event comparisons use wrap-aware differences, with intervals below
the corresponding signed half range.

Send fresh CLOCK packets before the first event (e.g. 10 Hz for one second) and
throughout a show (e.g. every 100–200 ms). CLOCK is the same compact format, command
9, ALL, event 0, execution low16 equal to sender low16, zero parameters. It updates
time only, uses no event slot and never changes output. Other valid targeted show
packets also provide clock samples. Audio phase is deliberately not the show clock:
it may reset at a pattern or beat change.

For a new forward-moving sender timestamp, the receiver measures
`offset = local_receive_ms - sender_ms - NK_SHOW_RX_COMPENSATION_MS`. It keeps the
smallest offset in each 2 s sampling window to reduce receive-delay jitter. A new
window tracks oscillator drift. The compile-time compensation defaults to 0 ms;
only tune it against measured gateway/RM2 latency. A controller can bootstrap from
an event alone, but fresh CLOCK warmup is required for useful multi-controller
alignment when an advertising controller has repeated an old payload.

**The sender must timestamp close to handing a new payload to its advertising
controller, and refresh timestamps regularly.** Legacy controller-generated
repeats of an unchanged payload are allowed: identical sender timestamps never
update the clock, and older event timestamps do not update it. A host/gateway stalled with an old payload cannot provide
fresh time. Air/driver latency is not knowable from the payload alone.

On sender replacement/reboot, send only freshly timestamped CLOCK packets for
**at least 3 seconds** before new events. After 2 seconds without a forward clock
sample, a different CLOCK timestamp can rebase the offset even if its value is
lower. Natural 32-bit wrap remains a forward sample. No session ID or controller
reset is required. Queued events retain their already frozen deadlines across a
rebase. Stop the previous advertiser completely: with no sender/session identity,
reordered traffic from two clock epochs cannot be distinguished reliably. Identical
stalled CLOCK advertisements never re-arm the clock. Warmup recovers the clock;
it does not cancel previously accepted commands (explicit show disable does).

On first acceptance, freeze the local deadline as `execute32 + estimated_offset`.
Later CLOCK samples and event retransmissions do not move an already queued event.
A refreshed retransmission keeps event ID, target, command, parameters and absolute
execution time; only sender time and CRC change. Stop retransmitting once the
execution time is more than 250 ms old. An unchanged advertisement repeated many
times still executes at most once.

There are **8 event slots** with no dynamic allocation or eviction. Events execute
in deadline order, equal deadlines in event-ID order. A full queue rejects new
events without marking them received, allowing retries after space is available.
The Link/PC owns the long timeline; these eight slots are only short lookahead.
Keep preparation events near their actual execution time instead of filling the
queue with an entire show. `show_full` counts capacity rejects; `show_stale` counts
out-of-horizon clock-mapping rejects. No acknowledgments are sent.

Dedupe is an equality cache of the **last 64 accepted/terminally late event IDs**,
plus all IDs still queued. There is no numeric-age rule, highest-ID lock, master ID
or session ID. Smaller unused IDs from a restarted/replacement sender are accepted;
65535→0 works normally. Repeats consume no slot and do not refresh cache position.
The same ID may be used again after 64 other remembered events and after its queued
event has left. Reusing an ID still in either set is a duplicate, even with changed
parameters; retransmission cannot modify an accepted event. This bounded cache is
not permanent replay protection: never retransmit an event after 64 subsequent IDs
have been accepted, and stop all retries 250 ms after its execution time.

**Sender startup: choose a random 16-bit initial event ID**, then increment modulo
65536 for each new event (including preparation). This minimizes collisions with
a receiver's recent cache after sender reboot; a collision is discarded until
its cached ID leaves the window. CLOCK event 0 is exempt from dedupe. IDs belong to
one coordinated show producer; none of this ordering/cache logic applies to
controller-sync sequences. Warm the restarted clock as described above.

An event at most **250 ms late** executes on the next loop pass; later arrivals or
events delayed longer in the queue are dropped and remembered. No catch-up replay.
PatternClock-based show patterns start with phase `now - original_local_deadline`,
so allowed late execution preserves intended phase. Events are consumed before
rendering the next frame. Normal frame budget is 120 FPS (~8.33 ms), plus loop,
radio and LED-transfer jitter; this is not a sub-millisecond timing guarantee.

## Commands and output authority

`p0..p6` denote packet bytes 15..21. Unlisted parameters must be zero.
Every command except CLOCK is scheduled and deduplicated, including preparation.

| ID | Command | Parameters | Effect at deadline |
| --- | --- | --- | --- |
| 1 | SET_PATTERN | p0 = 1..27 | Acquire pattern authority, run entry even for same ID; show phase begins at deadline |
| 2 | SET_BRIGHTNESS | p0 = 1..255 | Runtime brightness override; leaves selected output mode intact |
| 3 | SET_SOLID | p0 R, p1 G, p2 B, p3 brightness 0..255 | Static RGB across both logical strips; 0 retains/inherits runtime brightness |
| 4 | BLACKOUT | None | Explicit all-black output, independent of configured brightness |
| 5 | RELEASE | None | Return to current underlying output/brightness and invalidate pending image |
| 6 | CLEAR_PENDING | p0 image ID 0..255, p1 expected segment count 0..32 | Start black backbuffer of current logical length; clear received-index mask |
| 7 | SET_SEGMENT | p0 image ID, p1 index 0..31, p2 start, p3 count, p4 R, p5 G, p6 B | Change pending image only; nonzero count, within current logical LED range |
| 8 | APPLY_PENDING | p0 image ID | Copy a complete matching pending image to the visible static buffer atomically |
| 9 | CLOCK | None; special header rules above | Clock sample only, never an output event |

SET_PATTERN, SET_SOLID, BLACKOUT and APPLY_PENDING acquire output authority until
another output command or RELEASE. At acquisition they retain any show brightness,
or snapshot current underlying brightness. SET_BRIGHTNESS alone freezes only
brightness; underlying pattern selection can still follow sync. Local autoplay is
paused while any show override is active and restarts its interval at release.
Preparation alone does not acquire output authority or pause autoplay.

Underlying `currentPattern`, configured brightness, play mode and local clock are
not overwritten by show events. Existing pattern entry callbacks now initialize
render state without writing configuration. Controller-sync beacons continue to
update the underlying pattern, brightness and phase while show owns output; audio
V2 is still decoded. RELEASE therefore displays the current master state directly.
If a follower loses sync during override, its configured fallback-autoplay action
is deferred until release, allowing continued sync/audio reception in the meantime.
If the master returns before release, the pending fallback is cleared. Continue-local
and warning-only retain their existing behavior.

On a local controller, RELEASE resumes the underlying local selection/clock,
with clean pattern re-entry rather than restoring old LED pixels. Local button or
configuration edits during override can update that underlying selection. Existing
sensor/random/frame-driven patterns keep their behavior; a synchronized start is
not a promise that local motion or random effects produce identical pixels.

The final brightness limiter runs after show output and any pattern-specific
brightness effects. Critical battery caps remain at 95; lower runtime values remain
lower. Soft/emergency cutoff remains authoritative, blacks both physical outputs,
stops the radio and discards the show. USB recovery retains its existing path.
Battery/charging views retain display priority while active. Segment and solid RGB
bytes are unscaled 0..255 colors; final brightness scales
them once, equally on both strips. SET_SOLID p3=0 retains an existing show brightness
or snapshots `currentBrightness` on first output acquisition (the underlying
local/master setting, before pattern modulation or battery limiting). Later
sync brightness changes update the underlying value but not that snapshot. RELEASE
drops every show brightness override: followers use the latest received master
brightness, local controllers their current local brightness (including any local
edits during the show). Pattern-specific brightness behavior resumes normally.
Runtime brightness is never written into saved brightness; BLACKOUT does not change accepted config
brightness levels. Show reception suppresses periodic saves; explicit config save
and the existing safety cutoff save still save only ordinary configuration.

## Pending image semantics and strip addressing

One pending image and one visible static image, each at most 70 RGB entries. Logical
addresses are the existing contiguous firmware buffer, **not** fixed pin-buffer
offsets or a perimeter/ring mapping:

- `0 .. L-1`: strip 1, index 0 through L-1.
- `L .. 2L-1`: strip 2, index 0 through L-1.
- L is configured `strip_length` (10..35). Physical strip 2 still starts at offset
  35 in the physical buffer; unused physical pixels stay black.

To mirror a segment on both strips, send two segments at `start` and `L+start`.
No additional inversion is applied to static images. Segments may cross the
logical strip boundary. To make LEDs 0–7 red, 8–14 black and 15–24 blue, clear an
image expecting three segments, then set `(0,8,255,0,0)`, `(8,7,0,0,0)` and
`(15,10,0,0,255)` at segment indices 0,1,2. Send three more segments if the same
image should be mirrored on strip 2, and declare six expected segments instead.

Schedule CLEAR before all segments; schedule APPLY after all preparation. Each
segment index is accepted once for the current image. Overlaps use execution
order; prefer disjoint segments. Retransmissions of each preparation event must
reuse its original event ID. Missing CLEAR, wrong image ID, repeated segment index,
index >= declared count, out-of-range segments or changed strip length are rejected.
APPLY requires all indices `0..count-1`; otherwise visible output remains unchanged
and that Apply event is consumed. Repair with a new image transaction and new
Apply event. Zero segments produces a complete black image.

CLEAR and SET_SEGMENT never change the visible buffer. APPLY copies the whole
image before rendering; it leaves the pending image available until the next
CLEAR/RELEASE. RELEASE invalidates pending image but **does not cancel later queued
events**; this permits a sequence of show and autonomous sections. Explicit show
disable cancels the entire queue. Image IDs distinguish builds, not dedupe sessions;
do not recycle a build ID while its old commands are still in flight.

## Strict audio and autonomous sync contracts

Patterns 23–27 render only when V2 has `SIGNAL_VALID` (flags bit 1) and age
<=500 ms. `BEAT` (bit 0) marks a reported onset; `BEAT_LOCKED` (bit 2) alone
enables received BeatMs/phase and the derived beat pulse. Valid signal without
a beat lock still supplies energy and bands with zero phase/pulse. The central
`NK_AUDIO_FRESHNESS_TIMEOUT_MS` in `AudioPatternMath.h` is independent of the
1500 ms controller-sync loss timeout. At the slowest existing 5 Hz profile, 500 ms
allows two missing 200 ms frames plus 100 ms receive jitter margin; 10/20 Hz also
fit. Above 500 ms, the next render frame is black and filters reset. Identical
V2 payload repeats do not renew audio or revive expired data; a changed V2 payload
(e.g. incremented sequence/phase) is a new frame, with no sequence-order restriction.
V1 packets do not create or refresh an audio source; interleaved V1 does not discard a still-fresh
V2 source. Invalid/expired audio clears the logical LEDs and all smoothed audio
values. No synthetic spectrum, local beat, local PatternClock audio substitute or
old pixel animation remains. Reacquisition/entry initializes directly from current
received values and replaces pixel history on the first valid frame. Existing
valid-audio response, spatial design and local orientation colors are preserved.
Autoplay still selects 23–27 normally; without audio they remain black.

A follower accepts every valid pattern 1–27 from its sync group, even when locally
disabled. Mask edits do not evict a currently locked master's pattern. The local
mask still controls button cycling/autoplay. A sync master may autoplay; a locked
follower does not autoplay independently. Master sequence values may decrease or
restart, and no master UID/address pinning is performed. The existing persisted
`master_uid` compatibility field remains untouched and unenforced.

## Diagnostics

`show_status` is one ordinary NK4 response with the request's sequence. No unsolicited
show event logging occurs in timing/radio paths. All counters are runtime-only;
explicit session reset retains counters, reboot zeros them.

- Enable/authority: `show_supported`, `show_enabled`, `show_rx`, `show_active`,
  `show_output` (0 underlying, 1 pattern, 2 solid, 3 blackout, 4 buffer),
  `show_pattern` (selected pattern, or underlying in static mode), `show_brightness`.
- Events: `show_queue`, `show_last_event`, `show_last_cmd`, `show_executed`,
  `show_rejected`, `show_received`, `show_accepted`, `show_duplicates`, `show_stale`,
  `show_full`. Executed includes successful preparation; rejected includes
  incomplete/wrong-image commands. `show_stale` is a timing-horizon rejection,
  never numeric event-ID age. Received includes targeted CLOCK/retransmissions.
- Reception: `show_invalid`, `show_crc` (subset of invalid), `show_target_miss`.
  Malformed foreign/company traffic retains existing radio diagnostic handling.
- Timing: `show_late`, `show_dropped_late`, `show_clock_valid` (sample acquired,
  consult age for freshness), `show_clock_offset_ms`, `show_clock_age_ms`,
  `show_clock_samples`, `show_last_due_ms`, `show_lateness_ms`.
- Buffer: `show_pending`, `show_image`, `show_segments` (expected count),
  `show_segment_mask` (received indices, decimal uint32).

## Validation and remaining hardware checks

Run `python3 test/run_host_tests.py` for all assert checks (C++11, warnings as errors,
ASan/UBSan), then `pio run` for all three environments and `git diff --check`.
The integration harnesses compile selected actual `main.cpp` orchestration and
radio GAP dispatch functions against hardware doubles; they do not emulate the
MCU, BTstack or real LEDs. Radio state/advertising ownership and actual EEPROM
field I/O/migration are also exercised with hardware doubles. Audio checks include
loss/reacquisition between frames and stalled repeated advertisements.

Hardware checklist (not established by builds/host tests):

1. Legacy USB CLI and USB NK4: query/set/save/load, unchanged ranges and echoed seq;
   BLE GATT: notifications/newline framing, show enable then disconnect, USB recovery.
2. Two battery-powered controllers, no GATT: master autoplay through 1–27, follower
   mask only pattern 1 enabled. Check pattern/brightness/phase and no follower autoplay.
   Stop master, switch to a master with lower sequence; check takeover and all three
   configured sync-loss behaviors.
3. Send V2 plus interleaved Show packets: each of 23–27 renders, V1-only/startup and
   >500 ms audio loss black immediately; restart at very different audio levels.
   Test while show displays solid/blackout, then select an audio pattern and release.
4. CLOCK warmup, ALL/GROUP/SINGLE at one absolute deadline; measure both strips and
   multiple devices with a logic analyzer/camera. Repeat identical advertisements,
   refresh timestamps, reorder/drop packets, fill queue, test 250 ms late boundary.
5. Prepare disjoint segments across both strips. Check no intermediate display,
   incomplete-image rejection, matching image apply, strip lengths 10/25/35,
   release and explicit session reset. Reboot must not resume a show.
6. Measure clock drift/jitter over a full flight; tune receiver compensation only
   from measurements. Validate gateway timestamp refresh and legacy advertisement
   interval under interleaved audio/show traffic.
7. Controlled supply: low warning, critical cap under white/brightness 255,
   hysteresis, both cutoff paths and USB recovery. Check saved brightness unchanged.
8. Confirm master TX remains autonomous with show enable set, and GATT ownership
   is restored after leaving scanner mode. No Wi-Fi should start.

## Next task in nightkite-link

Implement the exact encoder/31-byte framing and CRC; fleet short-ID/group targeting;
a stable show clock with regularly refreshed CLOCK packets; event-ID allocation,
absolute deadlines, repetitions that preserve event identity, bounded sending rate
and deadline ordering; interleave unchanged Audio V2; build segment transactions
with image IDs/count/index and atomic APPLY; send RELEASE for autonomous sections;
provide preflight enable/save instructions, controller-reboot reconstruction and
diagnostics tooling. Randomize the initial event ID, increment modulo 65536, and
use a three-second fresh CLOCK warmup after sender restart. Keep fresh Audio V2
frames arriving well inside 500 ms; advance their sequence even for constant audio. Verify
fresh timestamp placement against the gateway BLE API and run the hardware checklist.
Do not reuse the controller-sync sequence counter as a master lock.

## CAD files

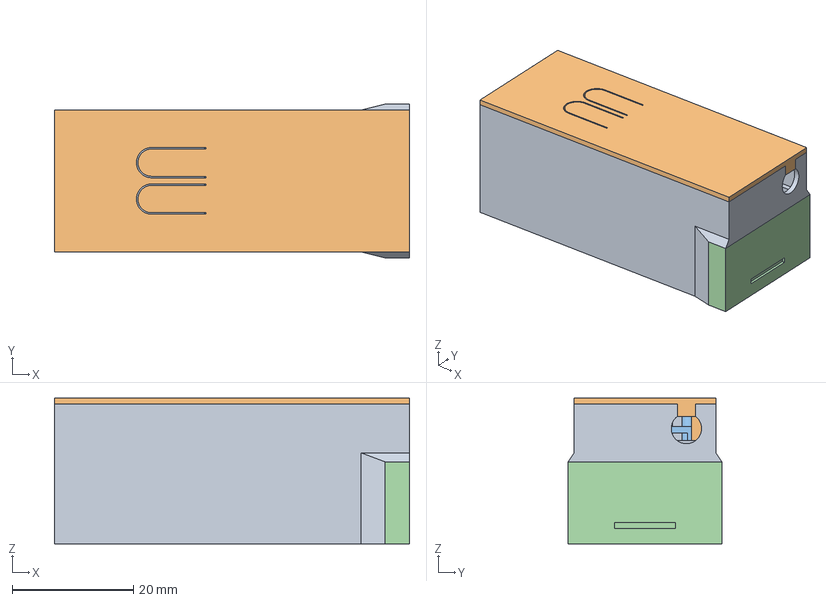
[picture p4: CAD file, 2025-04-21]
case/nightkite-multi.step
58.5 x 25.4 x 24.0 mm
Akkudeckel
Deckel
MPU6050 Clip
Komponente5

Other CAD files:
case/nightkite-multi.3mf

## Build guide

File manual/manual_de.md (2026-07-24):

# Bedienungsanleitung für die NightKite Multi LED-Drachenbeleuchtung (v3.0)

Willkommen bei deiner **NightKite Multi LED-Drachenbeleuchtung**!  
Dieses System bringt deinen Lenkdrachen im Dunkeln zum Leuchten, indem es dynamische LED-Effekte erzeugt, die auf die Bewegungen und Beschleunigungen deines Drachens reagieren.  
Die Farbe der LEDs wird überwiegend durch den aktuellen Winkel (Yaw) des Drachens bestimmt, während Geschwindigkeit, Helligkeit oder Fade je nach Muster von der Bewegungsintensität abhängen.  

Diese Anleitung hilft dir dabei, deine LED-Beleuchtung optimal zu nutzen.

---

## Inhaltsverzeichnis

1. [Überblick und Funktionen](#1-überblick-und-funktionen)  
   1. [Animations-Muster im Detail](#11-animations-muster-im-detail)  
2. [Komponenten](#2-komponenten)  
3. [Inbetriebnahme und Bedienung](#3-inbetriebnahme-und-bedienung)  
   1. [Controller einschalten und Initialisierung](#31-controller-einschalten-und-initialisierung)  
   2. [Funktionen des rechten Buttons](#32-funktionen-des-rechten-buttons)  
   3. [Ausschalten](#33-ausschalten)  
   4. [USB-CLI (Konfiguration)](#34-usb-cli-konfiguration)  
4. [Stromversorgung und Aufladen](#4-stromversorgung-und-aufladen)  
5. [Wichtige Hinweise](#5-wichtige-hinweise)

---

## 1. Überblick und Funktionen

Die NightKite Multi Beleuchtung bietet dir folgende Kernfunktionen:

- **Bewegungsreaktive Beleuchtung:**  
  Die LEDs passen Farbe und Animationsdynamik an die Flugbewegungen deines Drachens an  
  *(Winkel → Farbe, Bewegung → Tempo/Fade/Helligkeit – je nach Muster)*.
- **Helligkeitsstufen:**  
  Sechs Helligkeitsstufen (95 → 255 in Schritten von 32), beeinflussen auch die Akkulaufzeit.
- **Animations-Muster:**  
  27 vordefinierte Animations-Muster, davon fünf experimentelle V2-Audio-Sync-Patterns (ebenfalls Einfluss auf die Laufzeit).
- **Autoplay:**  
  Optionales automatisches Durchschalten durch aktivierte Pattern mit einstellbarem globalem Intervall.
- **Ladestandsanzeige:**  
  Zeigt den aktuellen Akkustand direkt über das LED-Band an.
- **Speicherfunktion:**  
  Muster, Helligkeit, Strip-Länge, Motion-Smoothing, Sensor-Ranges, Boot-Kalibrierung und MPU-Offsets werden persistent gespeichert.
- **USB-CLI:**  
  USB-Serielles Interface für Konfiguration, Diagnose, Timing und Kalibrierung.

---

### 1.1. Animations-Muster im Detail

Die aktuelle NightKite-Multi-Firmware verfügt über 27 vordefinierte Animationsmuster, die per Doppelklick gewechselt werden.
Nach dem Einschalten (und der Kalibrierung) startet der Controller mit dem zuletzt verwendeten Muster und der zuletzt gewählten Helligkeit.  
Beim ersten Start: **Pattern-ID 1**, **Helligkeit 95**.

1. **Regenbogen-Muster:** Sanfter, kontinuierlicher Rainbow-Durchlauf über das gesamte Band. Nicht bewegungsreaktiv.  
2. **Voller String, Winkel-Farbe:** Gesamter LED-String leuchtet in einer Farbe entsprechend dem aktuellen Winkel (Yaw).  
3. **Voller String, Winkel-Farbe & Bewegungs-Helligkeit:** Wie (2), aber Helligkeit folgt der Bewegungsintensität.  
4. **LED-Lauflicht (fix) mit Fadeout, Winkel-Farbe:** Ein einzelner Punkt wandert mit fester Geschwindigkeit; Farbe = Winkel, sanfter Fadeout.  
5. **LED-Lauflicht (reaktiv) mit Fadeout-Speed, Winkel-Farbe:** Wie (4), aber Tempo und Fade-Geschwindigkeit reagieren auf Bewegung.  
6. **LED-Lauflicht zweifarbig (reaktiv), Winkel-Farbe:** Wie (5), jedoch mit zweifarbigem Schweif; Tempo & Fade bewegungsabhängig.  
7. **Heartbeat (Winkel-Farbe):** Pulsierende „Herzschlag“-Animation über das Band; Farbe = Winkel.  
8. **Ping-Pong (bouncing) mit reaktivem Fade:** Punkt läuft vor / zurück; Fadeout hängt von Bewegung ab.  
9. **Comet-Swarm (4 Kometen):** Vier Kometen jagen über die aktuell konfigurierte Gesamtlänge (beide Hälften gespiegelt). Farbe = Winkel.  
10. **Breath / Storm (adaptiv):**  
    - Ruhig: weiches „Atmen“ (Helligkeits-Sinus).  
    - Unruhig: „Sturm“ mit Funken, deren Anzahl mit der Bewegung zunimmt.  
11. **Jerk-Wave (Ruck-Welle):** Bewegung löst Welle von der Mitte zu den Enden aus; Farbe = Winkel.  
12. **Yaw-Spinner (mit Richtungs-Gedächtnis):** Lichtkopf mit Blur-Schweif folgt der Drehrate (Yaw-Rate) mit Totzone. Farbe = Winkel.  
13. **Yaw-Spinner Kreis:** Variante von (12), bei der der Lichtkopf optisch ringförmig über beide Strips umläuft. Die Richtung folgt weiter der Yaw-Rate; Farbe = Winkel.  
14. **LED-Lauflicht zweifarbig (reaktiv, invertiert):** Wie (6), aber Laufrichtung invertiert.
15. **Palette-Beat Motion:** Pulsierendes Palettenmuster nach dem Vorbild von FastLED PaletteBeat. Der Yaw-Winkel bestimmt die Grundfarbfamilie, die Bewegungsintensität verändert Pulsrate und Farbabstand, und Yaw-Bewegung schiebt die optische Flussrichtung an.
16. **Pacifica Kite:** Mehrlagige, ozeanartige Wellen mit weichen Whitecaps. Bewegung erhöht die Wellenenergie; Yaw verschiebt die kühle Farbwelt.
17. **Twinkle Motion:** Sanfte Sternen-/Funken-Twinkles auf dunkler Grundfläche. Mehr Bewegung erhöht Dichte und Helligkeit.
18. **Fire Jet:** Feuerartige Energie, die sich aus der Mitte aufbaut und über das Band verteilt. Bewegung bestimmt die Intensität der Funken.
19. **Noise Ring:** Fließendes, Noise-basiertes Ringmuster mit bewegungs- und yawgesteuerter Farbdynamik.
20. **Pride Yaw:** Weiche, satte Farbströme mit Yaw-abhängigem Farbversatz und bewegungsabhängigem Tempo.
21. **Confetti Jerk:** Ruhiger Grundschein mit hellen Konfetti-Ausbrüchen bei harten Bewegungsimpulsen.
22. **Center Ripple:** Klar erkennbare Wellen laufen nach Bewegungsimpulsen von der Mitte nach außen.
23. **Audio Pulse Angle Color:** Synchroner Ganzband-Puls; Energy und Bass steuern Helligkeit und Flash, Yaw/Pitch die lokale Farbe.
24. **Audio Spectrum Ribbon:** Ein phasensynchrones Band kombiniert Bass-Grundglühen, Mittenwelle und Höhenakzente.
25. **Audio Beat Ripples:** Beat- und Bass-gesteuerte Ringe laufen synchron von der Strip-Mitte nach außen.
26. **Audio Band Comets:** Zwei breite, gegenläufige Bass-/Mitten-Kometen laufen synchron; Höhen setzen dezente Akzente.
27. **Audio Beat Mosaic:** Drei bis fünf große, gespiegelte Farbzonen reagieren weich auf Beat, Energie und Frequenzbänder.

Die Patterns 23 bis 27 benötigen für echte Audioreaktion V2-Audio-Beacons. Bei V1 oder fehlenden V2-Daten laufen sie mit einem weichen, sichtbaren Fallback weiter.

Bei Sync-Verlust läuft `continue_local` mit dem letzten Pattern weiter, `fallback_autoplay` wechselt zu lokalem Autoplay und `warning_only` zeigt eine rote Loss-Warnung in der Statusanzeige. `get section=sync` trennt das Sync-Ziel `sync_pattern` vom tatsächlich gerenderten `local_pattern`.

**Audio-Sync-Hardwaretest:** Controller als Follower in dieselbe Sync-Gruppe wie den Cardputer setzen, bei alten Pattern-Masken `enable_pattern 23,24,25,26,27` ausführen und am Cardputer `V2 Mic Full` starten. Mit `NK4 seq=20 cmd=audio_sync_status` und `NK4 seq=10 cmd=get section=sync` müssen unter anderem `audio_valid=1`, `last_beacon_version=2`, steigendes `scan_decode_v2`, `sync_locked=1` und `scan_crc_fail=0` sichtbar sein.

---

## 2. Komponenten

Die NightKite Multi Beleuchtung besteht aus:

- **Mikrocontroller:** Pimoroni Pico LiPo mit integriertem Akku-Management (USB-C)  
- **Akku:** 500 mAh LiPo-Akku, direkt am Mikrocontroller  
- **Sensor:** MPU6050 (Gyroskop / Beschleunigungsmesser) für Lage (Yaw / Pitch / Roll) und Bewegung  
- **LED-Strips:** Zwei symmetrische Stränge mit gleicher Länge (konfigurierbar per CLI, 10 bis 35 Pixel pro Strang), WS281x / „Fairy-String“, GRB-Reihenfolge

---

## 3. Inbetriebnahme und Bedienung

### 3.1. Controller einschalten und Initialisierung

Der Controller besitzt zwei Tasten: **links** und **rechts**.

1. **Einschalten:** Linken Button drücken.  
2. **Initialisierung:** Nach dem Einschalten wird die gespeicherte Konfiguration geladen. Standardmäßig erfolgt anschließend eine kurze Quick-Kalibrierung des MPU6050.  
   Halte den Controller ruhig, um saubere Sensor-Offsets zu ermitteln.  
3. **Bereitschaft:** Nach Abschluss der Kalibrierung schalten sich die LEDs ein.  
   Das System startet mit zuletzt verwendetem Muster und Helligkeit  
   *(bei Erstbetrieb: Pattern-ID 1, Helligkeit 95)*.

---

### 3.2. Funktionen des rechten Buttons

Der rechte Button ist ein **Multifunktions-Button**:

- **Muster / Animation wechseln (Doppelklick):**  
  → Zyklischer Wechsel zum nächsten aktivierten Muster.
- **Autoplay umschalten (Doppelklick in der Akkuanzeige):**  
  → Schaltet Autoplay global ein oder aus.
- **Helligkeitsstufe ändern (kurz drücken):**  
  → Nur während die Akkuanzeige aktiv ist.  
    Nächste der 6 Helligkeitsstufen: 95 → 127 → 159 → 191 → 223 → 255 → 95.
- **Akkuladestand anzeigen (gedrückt halten):**  
  → Zeigt den Akkustand auf dem Haupt-Strip an.  
    Auf dem zweiten Strip blinkt eine blaue LED-Marke; zusätzlich zeigen gelbe LEDs die aktuelle Helligkeitsstufe (6 Stufen) an, und zwei weitere Status-LEDs dahinter zeigen den Autoplay-Status (`grün/grün` = an, `rot/rot` = aus).  
    Die Rückkehr zum zuletzt aktiven Muster erfolgt 5 Sekunden nach der letzten Interaktion in der Akkuanzeige.

**Skala der Akkuanzeige (prozentbasiert):**

| Anzeige | Ladezustand | Farbe |
|---|---|---|
| 5 LEDs  | ≥ 80% | Blau |
| 4 LEDs  | ≥ 60% | Grün |
| 3 LEDs  | ≥ 40% | Grün |
| 2 LEDs  | ≥ 20% | Gelb |
| 1 LED | ≥ 8% | Gelb |
| 1 LED blinkend | < 8% | Rot |

---

### 3.3. Ausschalten

- **Ausschalten:** Linken Button erneut drücken.

---

### 3.4. USB-CLI (Konfiguration)

Sobald eine aktive serielle USB-Verbindung besteht, ist die CLI verfügbar.

- Prompt: `nk>`
- Hilfe: `help`
- Aktuelle Werte: `show`
- Einzelwert lesen: `get pattern`, `get brightness`, `get strip_length`, `get smoothing`, `get accel_range`, `get gyro_range`, `get boot_calibration`, `get enabled_patterns`, `get inverted_patterns`, `get autoplay`, `get autoplay_interval`
- Einzelwert setzen:
  - `set pattern <1..27>`
  - `set brightness <95|127|159|191|223|255>`
  - `set strip_length <10..35>`
  - `set smoothing <1..512>`
  - `set accel_range <2|4|8|16>`
  - `set gyro_range <250|500|1000|2000>`
  - `set boot_calibration <off|quick>`
  - `set autoplay <on|off>`
  - `set autoplay_interval <1..300>`
- Pattern-Auswahl:
  - `patterns`
  - `enable_pattern <1..27[,id...]>`
  - `disable_pattern <1..27[,id...]>`
  - `invert_pattern <1..27[,id...]>`
  - `normal_pattern <1..27[,id...]>`
- Diagnose:
  - `battery`
  - `sensor`
  - `timing`
  - `timing reset`
  - `offsets`
- Kalibrierung:
  - `calibrate quick`
  - `calibrate precise`
- Speichern/Laden:
  - `save` (sofort in EEPROM schreiben)
  - `load` (aus EEPROM laden)
  - `defaults` (Standardwerte laden, noch nicht speichern)
  - `reboot` / `restart`

Hinweise:
- Daten-Kommandos antworten konsistent mit `OK ...` oder `ERR ...`. Beispiel: `OK pattern=1`.
- `show` liefert alle relevanten Konfigurationswerte als kompakte `key=value`-Zeile.
- `show` enthält auch den aktuellen Autoplay-Status und das Autoplay-Intervall.
- `patterns` zeigt alle Pattern mit Status `on` oder `off`.
- `strip_length` gilt immer für beide Strips gleichzeitig (symmetrisch).
- `set pattern` schaltet das aktive Muster sofort um.
- `set pattern` darf auch deaktivierte Pattern direkt anwählen.
- Ein manueller Patternwechsel lässt Autoplay aktiv, setzt aber den Autoplay-Timer zurück.
- `set brightness` wirkt sofort.
- `set strip_length` wirkt sofort auf beide Strips.
- `enable_pattern` und `disable_pattern` steuern, welche Pattern per Doppelklick durchgeschaltet werden.
- Beide Befehle akzeptieren auch mehrere Pattern gleichzeitig als kommagetrennte Liste, z. B. `disable_pattern 3,5,7`.
- `invert_pattern` und `normal_pattern` steuern die Laufrichtung pro Pattern und speichern diese Einstellung persistent.
- Auch diese beiden Befehle akzeptieren mehrere Pattern gleichzeitig als kommagetrennte Liste, z. B. `invert_pattern 4,12,13`.
- Nicht jedes Pattern besitzt eine sichtbare Laufrichtung. Bei unterstützten Patterns kehrt die Option die Bewegungsrichtung um.
- Es muss immer mindestens ein Pattern aktiv bleiben.
- Autoplay verwendet nur aktivierte Pattern.
- Autoplay kann persistent gespeichert werden und startet nach dem Booten automatisch, wenn es gespeichert eingeschaltet war.
- `smoothing`, `accel_range`, `gyro_range` und `boot_calibration` greifen erst nach einem Neustart. Die CLI kennzeichnet das in der Antwort mit `(applies after reboot)`.
- `timing` zeigt `FastLED`-FPS, `loop`-/`work`-Zeiten, Frame-Budget und Sample-Anzahl in Mikrosekunden.
- `battery` zeigt zusätzlich `battery_percent` und `battery_state`.
- `timing reset` setzt die Timing-Statistik (`avg`, `max`, `samples`) zurück, damit einzelne Pattern oder Änderungen direkt vergleichbar sind.
- `offsets` zeigt die aktuell verwendeten MPU-Offsets.
- `calibrate quick` ist die schnelle Alltags-Kalibrierung und speichert die gefundenen Offsets.
- `calibrate precise` nutzt den deutlich langsameren `IMU_Zero`-basierten Präzisionspfad und speichert die gefundenen Offsets.
- `calibrate quick` und `calibrate precise` starten mit `OK calibrate_started=1 ...` und enden mit `OK calibrate_finished=1 ...` plus einer finalen Offset-Zeile.
- Im USB-Machine-Modus wird `NK4 seq=<id> cmd=calibrate mode=quick|precise` verwendet. NK4 sendet nach dem Speichern genau eine Antwort mit derselben Sequenz; BLE GATT weist diese blockierende Wartungsfunktion mit `unsupported usb_only` ab.
- `defaults` lädt die Standardwerte nur in den Arbeitsspeicher. Für dauerhafte Speicherung ist anschließend `save` nötig.
- Beim nächsten Neustart werden die gespeicherten Werte automatisch geladen.

## 4. Stromversorgung und Aufladen

Das System wird durch einen integrierten **500 mAh LiPo-Akku** versorgt.  
Der Pimoroni Pico LiPo besitzt ein intelligentes Lade-/Entlademanagement.

- **Aufladen:** Über USB-C an PC oder Netzteil anschließen.  
- **Lade-Anzeige:** Während des Ladens zeigt das Band den Füllstand als Balken;  
  eine rote LED blinkt während des aktiven Ladevorgangs.  
- **USB-CLI aktiv:** Bei aktiver serieller Verbindung wird die Ladeanzeige unterdrückt, damit die CLI störungsfrei genutzt werden kann.  
- **Automatischer Rückwechsel:** Nach dem Trennen vom USB kehrt das System zum letzten Muster zurück.  
- **Laufzeit:** Je nach Muster und Helligkeit ca. 1 – 2,5 Stunden.

**Akkuwarnungen und Schutzverhalten:**

- Der Ladezustand wird über eine NightKite-spezifische LiPo-SoC-Kurve berechnet und geglättet.
- Unter 3.40 V für ca. 15 s meldet die Diagnose `LOW_WARNING`.
- Unter 3.30 V für ca. 10 s meldet die Diagnose `CRITICAL`; die Helligkeit wird temporär auf `MIN_BRIGHTNESS` begrenzt, ohne den gespeicherten Helligkeitswert zu ändern.
- Unter 3.20 V für ca. 15 s geht der Controller in `SOFT_CUTOFF`: LEDs schwarz, Konfiguration defensiv gespeichert, keine Pattern-/Wireless-Aktivität mehr.
- Unter ca. 3.08 V wird sofort `EMERGENCY_CUTOFF` aktiv.
- USB-Betrieb und Laden lösen keinen Low-Battery-Cutoff aus.

**Speicherfunktion (automatisch):**

- Muster und Helligkeit werden etwa alle 5 Minuten geprüft und bei Änderung gespeichert.  
- Strip-Länge wird ebenfalls geprüft und bei Änderung gespeichert.  
- Motion-Smoothing, Sensor-Ranges, Boot-Kalibrierung und MPU-Offsets werden ebenfalls überwacht und bei Änderung gespeichert.
- Beim nächsten Start werden diese Werte automatisch wiederhergestellt.

---

## 5. Wichtige Hinweise

- **Ruhige Initialisierung:** Nach dem Einschalten ruhig halten, bis LEDs aktiv sind.  
- **Präzise Kalibrierung:** Für `calibrate precise` den Controller auf eine absolut ruhige, waagerechte Fläche legen und wenn möglich vorher 5-10 Minuten thermisch stabilisieren.  
- **Wetterbedingungen:** Elektronik vor Feuchtigkeit schützen (kein Regen / Nebel).  
- **Sicherheit:** Bei Nachtflügen ausreichenden Abstand halten und freie Fläche wählen.  
- **Akku-Pflege:** Nur geeignete USB-Netzteile verwenden.  
  Akku nicht unbeaufsichtigt laden, nicht kurzschließen, nicht beschädigen oder tiefentladen.

---

**Kurzüberblick für den schnellen Einstieg:**  
`Einschalten → ruhig halten (Kalibrierung) → Doppelklick = Muster → Langdruck = Akkuanzeige → Kurztipp (in Akkuanzeige) = Helligkeit → Doppelklick (in Akkuanzeige) = Autoplay`

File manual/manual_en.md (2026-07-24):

# User Manual for the NightKite Multi LED Kite Lighting (v3.0)

Welcome to your **NightKite Multi LED Kite Lighting System**!  
This system brings your stunt kite to life at night by generating dynamic LED effects that respond to the kite’s movement and acceleration.  
The LED color is primarily determined by the kite’s current yaw angle, while speed, brightness, or fade depend on motion intensity and the selected pattern.  

This guide will help you get the most out of your LED lighting system.

---

## Table of Contents

1. [Overview and Features](#1-overview-and-features)  
   1. [Animation Patterns in Detail](#11-animation-patterns-in-detail)  
2. [Components](#2-components)  
3. [Operation and Controls](#3-operation-and-controls)  
   1. [Power On and Initialization](#31-power-on-and-initialization)  
   2. [Functions of the Right Button](#32-functions-of-the-right-button)  
   3. [Power Off](#33-power-off)  
   4. [USB CLI (Configuration)](#34-usb-cli-configuration)  
4. [Power Supply and Charging](#4-power-supply-and-charging)  
5. [Important Notes](#5-important-notes)

---

## 1. Overview and Features

The NightKite Multi lighting system offers the following core features:

- **Motion-Reactive Lighting:**  
  LEDs adapt their color and animation dynamics to the kite’s flight movements  
  *(Angle → Color, Motion → Speed/Fade/Brightness, depending on the pattern)*.
- **Brightness Levels:**  
  Six selectable brightness levels (95 → 255 in steps of 32), which also affect battery life.
- **Animation Patterns:**  
  27 predefined animation modes, including five experimental V2 audio-sync patterns (each affects runtime differently).
- **Autoplay:**  
  Optional automatic cycling through enabled patterns with a configurable global interval.
- **Battery Indicator:**  
  Displays the current battery level directly via the LED strip.
- **Memory Function:**  
  Pattern, brightness, strip length, motion smoothing, sensor ranges, boot calibration, and MPU offsets are stored persistently.
- **USB CLI:**  
  USB serial interface for configuration, diagnostics, timing, and calibration.

---

### 1.1. Animation Patterns in Detail

The current NightKite Multi firmware includes 27 predefined animation patterns that can be changed with a double-click.
After powering on and calibration, the controller starts with the last used pattern and brightness level.  
On first startup: **Pattern ID 1**, **Brightness 95**.

1. **Rainbow Pattern:** Smooth, continuous rainbow cycle across the strip. Not motion-reactive.  
2. **Full String, Angle-Color:** Entire LED strip glows in a color determined by the current yaw angle.  
3. **Full String, Angle-Color & Motion Brightness:** Like (2), but brightness follows motion intensity.  
4. **LED Runner (fixed) with Fadeout, Angle-Color:** A single light point moves at fixed speed; color = angle, smooth fadeout.  
5. **LED Runner (reactive) with Fadeout-Speed, Angle-Color:** Like (4), but speed and fade respond to motion.  
6. **LED Runner (dual-color, reactive), Angle-Color:** Like (5), but with a two-color trail; speed and fade depend on movement.  
7. **Heartbeat (Angle-Color):** Pulsating heartbeat animation; color = angle.  
8. **Ping-Pong (bouncing) with reactive fade:** Point moves back and forth; fadeout duration increases with motion.  
9. **Comet Swarm (4 Comets):** Four short comets race across the currently configured total length (both halves mirrored). Color = angle.  
10. **Breath / Storm (adaptive):**  
    - Calm: smooth “breathing” (brightness sinus).  
    - Turbulent: “storm” with sparks that increase with movement.  
11. **Jerk Wave:** Sudden motion triggers a wave from the center to the ends; wave speed increases with motion; color = angle.  
12. **Yaw Spinner (with direction memory):** Light head with blurred trail follows yaw rate with small dead zone to prevent flicker; color = angle.  
13. **Yaw Spinner Circle:** Variant of (12) where the light head appears to travel in a circular loop across both strips. Direction still follows yaw rate; color = angle.  
14. **LED Runner (dual-color, reactive, inverted):** Like (6), but with inverted running direction.
15. **Palette Beat Motion:** A pulsing palette pattern inspired by FastLED PaletteBeat. Yaw sets the base color family, movement intensity changes pulse rate and palette spread, and yaw movement nudges the apparent flow direction.
16. **Pacifica Kite:** Layered ocean-like waves with soft whitecaps. Motion increases wave energy; yaw shifts the cool color family.
17. **Twinkle Motion:** Soft star-like twinkles on a dim base glow. Motion increases twinkle density and brightness.
18. **Fire Jet:** Fire-like energy building from the center and spreading through the strip. Motion controls spark intensity.
19. **Noise Ring:** Flowing noise-based ring texture with palette movement driven by motion and yaw.
20. **Pride Yaw:** Smooth, saturated flowing rainbow bands with yaw-based hue offset and motion-dependent pace.
21. **Confetti Jerk:** Calm glow with bursts of bright confetti when the kite gets sharp motion impulses.
22. **Center Ripple:** Clear ripple waves starting from the middle and running outward after motion impulses.
23. **Audio Pulse Angle Color:** A synchronized full-strip pulse; energy and bass drive brightness while yaw/pitch set local color.
24. **Audio Spectrum Ribbon:** A phase-synchronized ribbon combining a bass glow, mid wave, and treble highlights.
25. **Audio Beat Ripples:** Beat- and bass-driven rings travel outward from the center of each strip.
26. **Audio Band Comets:** Two broad, counter-moving bass/mid comets run in sync while treble adds restrained accents.
27. **Audio Beat Mosaic:** Three to five large mirrored color zones react smoothly to beat, energy, and frequency bands.

Patterns 23 through 27 need V2 audio beacons for live audio response. With V1 or missing V2 data, they continue with a smooth visible fallback.

On sync loss, `continue_local` keeps the last pattern running, `fallback_autoplay` switches to local autoplay, and `warning_only` shows a red loss warning in the status view. `get section=sync` separates the sync target in `sync_pattern` from the rendered `local_pattern`.

**Audio-sync hardware test:** Put the controller in follower mode with the same sync group as the Cardputer, run `enable_pattern 23,24,25,26,27` for an older saved pattern mask, and start `V2 Mic Full` on the Cardputer. `NK4 seq=20 cmd=audio_sync_status` and `NK4 seq=10 cmd=get section=sync` should show `audio_valid=1`, `last_beacon_version=2`, increasing `scan_decode_v2`, `sync_locked=1`, and `scan_crc_fail=0`.

---

## 2. Components

The NightKite Multi lighting system consists of the following main components:

- **Microcontroller:** Pimoroni Pico LiPo with integrated battery management (USB-C)  
- **Battery:** 500 mAh LiPo battery connected directly to the microcontroller  
- **Sensor:** MPU6050 (gyroscope/accelerometer) to detect orientation (Yaw/Pitch/Roll) and motion  
- **LED Strips:** Two symmetric strings with equal length (configurable via CLI, 10 to 35 pixels per string), WS281x / “fairy string”, GRB order

---

## 3. Operation and Controls

### 3.1. Power On and Initialization

The controller has two buttons: **left** and **right**.

1. **Power On:** Press the left button.  
2. **Initialization (Calibration):** After power-on, the stored configuration is loaded. By default, a short MPU6050 quick calibration then starts automatically.  
   Hold the controller still for a few seconds to ensure accurate sensor offsets.  
3. **Ready:** After calibration, the LEDs turn on.  
   The system starts with the last used pattern and brightness  
   *(on first use: Pattern ID 1, Brightness 95)*.

---

### 3.2. Functions of the Right Button

The right button is a **multi-function control**:

- **Change Pattern / Animation (double-click):**  
  → Cycles through the next enabled animation pattern.
- **Toggle Autoplay (double-click while the battery display is active):**  
  → Turns autoplay on or off globally.
- **Change Brightness (short press):**  
  → Only while the battery display is active.  
    Switches through the six brightness levels: 95 → 127 → 159 → 191 → 223 → 255 → 95.
- **Show Battery Level (hold):**  
  → Shows the battery level on the main strip.  
    On the second strip, a blue marker LED flashes, yellow LEDs show the current brightness step (6 levels), and two additional status LEDs behind them show autoplay state (`green/green` = on, `red/red` = off).  
    Return to the previously active pattern happens 5 seconds after the last interaction in the battery display.

**Battery Level Scale (percentage-based):**

| Indicator | State of charge | Color |
|---|---|---|
| 5 LEDs | ≥ 80% | Blue |
| 4 LEDs | ≥ 60% | Green |
| 3 LEDs | ≥ 40% | Green |
| 2 LEDs | ≥ 20% | Yellow |
| 1 LED | ≥ 8% | Yellow |
| 1 blinking LED | < 8% | Red |

---

### 3.3. Power Off

- **Power Off:** Press the left button again to turn the controller off.

---

### 3.4. USB CLI (Configuration)

As soon as an active USB serial connection exists, the CLI is available.

- Prompt: `nk>`
- Help: `help`
- Show current values: `show`
- Read single value: `get pattern`, `get brightness`, `get strip_length`, `get smoothing`, `get accel_range`, `get gyro_range`, `get boot_calibration`, `get enabled_patterns`, `get inverted_patterns`, `get autoplay`, `get autoplay_interval`
- Set single value:
  - `set pattern <1..27>`
  - `set brightness <95|127|159|191|223|255>`
  - `set strip_length <10..35>`
  - `set smoothing <1..512>`
  - `set accel_range <2|4|8|16>`
  - `set gyro_range <250|500|1000|2000>`
  - `set boot_calibration <off|quick>`
  - `set autoplay <on|off>`
  - `set autoplay_interval <1..300>`
- Pattern selection:
  - `patterns`
  - `enable_pattern <1..27[,id...]>`
  - `disable_pattern <1..27[,id...]>`
  - `invert_pattern <1..27[,id...]>`
  - `normal_pattern <1..27[,id...]>`
- Diagnostics:
  - `battery`
  - `sensor`
  - `timing`
  - `timing reset`
  - `offsets`
- Calibration:
  - `calibrate quick`
  - `calibrate precise`
- Save/load:
  - `save` (write immediately to EEPROM)
  - `load` (load from EEPROM)
  - `defaults` (load defaults, not saved yet)
  - `reboot` / `restart`

Notes:
- Data commands reply consistently with `OK ...` or `ERR ...`. Example: `OK pattern=1`.
- `show` returns all relevant configuration values as a compact `key=value` line.
- `show` also includes the current autoplay state and autoplay interval.
- `patterns` lists all patterns with `on` or `off` state.
- `strip_length` always applies to both strips together (symmetric).
- `set pattern` switches the active pattern immediately.
- `set pattern` can also select patterns that are currently disabled for button cycling.
- A manual pattern change keeps autoplay enabled, but resets the autoplay timer.
- `set brightness` takes effect immediately.
- `set strip_length` applies immediately to both strips.
- `enable_pattern` and `disable_pattern` control which patterns are included when cycling with the button.
- Both commands also accept multiple pattern IDs as a comma-separated list, for example `disable_pattern 3,5,7`.
- `invert_pattern` and `normal_pattern` control the animation direction per pattern and store that setting persistently.
- These commands also accept multiple pattern IDs as a comma-separated list, for example `invert_pattern 4,12,13`.
- Not every pattern has a visually meaningful direction. On supported patterns, this option reverses the animation movement.
- At least one pattern must always remain enabled.
- Autoplay cycles only through enabled patterns.
- Autoplay can be stored persistently and starts automatically after boot if it was saved as enabled.
- `smoothing`, `accel_range`, `gyro_range`, and `boot_calibration` only take effect after reboot. The CLI marks this in the reply with `(applies after reboot)`.
- `timing` reports `FastLED` FPS, `loop`/`work` times, frame budget, and sample count in microseconds.
- `battery` also reports `battery_percent` and `battery_state`.
- `timing reset` clears the timing statistics (`avg`, `max`, `samples`) so individual patterns or changes can be compared directly.
- `offsets` reports the currently active MPU offsets.
- `calibrate quick` is the fast everyday calibration path and saves the resulting offsets.
- `calibrate precise` uses the much slower `IMU_Zero`-style precision path and saves the resulting offsets.
- `calibrate quick` and `calibrate precise` start with `OK calibrate_started=1 ...` and finish with `OK calibrate_finished=1 ...` plus a final offset line.
- In USB machine mode, use `NK4 seq=<id> cmd=calibrate mode=quick|precise`. NK4 sends one sequence-matched completion after saving; BLE GATT rejects this blocking maintenance operation with `unsupported usb_only`.
- `defaults` loads the default values into working memory only. Run `save` afterwards if you want to keep them permanently.
- Saved values are restored automatically after restart.

## 4. Power Supply and Charging

The system is powered by an integrated **500 mAh LiPo battery**.  
The Pimoroni Pico LiPo features intelligent charging and power management.

- **Charging:** Connect via USB-C to a PC or USB power adapter.  
- **Charging Indicator:** While charging, the LED strip shows the charge level as a bar;  
  a red LED blinks during the active charging process.  
- **USB CLI active:** While a serial session is active, the charging display is suppressed so CLI usage stays predictable.  
- **Automatic Return:** After disconnecting USB, the system automatically returns to the last active pattern.  
- **Runtime:** Typically between 1 – 2.5 hours depending on brightness and pattern.

**Battery warnings and protection behavior:**

- State of charge is calculated from a NightKite-specific LiPo SoC curve and smoothed.
- Below 3.40 V for about 15 s, diagnostics report `LOW_WARNING`.
- Below 3.30 V for about 10 s, diagnostics report `CRITICAL`; brightness is temporarily capped to `MIN_BRIGHTNESS` without changing the saved brightness value.
- Below 3.20 V for about 15 s, the controller enters `SOFT_CUTOFF`: LEDs black, configuration defensively saved, and no pattern/wireless activity.
- Below about 3.08 V, `EMERGENCY_CUTOFF` is entered immediately.
- USB operation and charging do not trigger low-battery cutoff.

**Automatic Memory Function:**

- Pattern and brightness are checked roughly every 5 minutes and saved if changed.  
- Strip length is also checked and saved if changed.  
- Motion smoothing, sensor ranges, boot calibration, and MPU offsets are also tracked and saved when changed.
- On the next startup, the last saved values are automatically restored.

---

## 5. Important Notes

- **Keep Still During Initialization:** After powering on, keep the controller still until the LEDs activate.  
- **Precise Calibration:** For `calibrate precise`, place the controller on a perfectly still, level surface and ideally let it thermally stabilize for 5-10 minutes beforehand.  
- **Weather Conditions:** Designed for use on stunt kites; protect electronics from moisture (no rain or fog).  
- **Safety:** Night flights require extra attention. Keep a safe distance from people, trees, power lines, and roads.  
- **Battery Care:** Charge only with suitable USB power supplies.  
  Do not leave the battery unattended while charging. Do not short-circuit, puncture, or deep-discharge.

---

**Quick Start Summary:**  
`Power On → Hold Still (Calibration) → Double-Click = Pattern → Long Press = Battery Display → Short Press (in battery display) = Brightness → Double-Click (in battery display) = Autoplay`

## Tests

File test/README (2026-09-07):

Host assert checks (requires Python 3 and a C++11 compiler, no test framework):

    python3 test/run_host_tests.py

The runner builds every test/*/test_*.cpp with warnings as errors, AddressSanitizer
and UndefinedBehaviorSanitizer in a temporary directory. CXX selects the compiler.
It also extracts actual main.cpp orchestration and GAP dispatch functions into
host harnesses with hardware doubles to check sync/show/audio/render integration,
radio ownership and EEPROM field migration. These checks
do not simulate BTstack, the FSM library, sensors, LED timing or physical power.

Firmware validation, all supported environments:

    pio run
    git diff --check

Show protocol and hardware checklist: docs/show-control-v1.md.

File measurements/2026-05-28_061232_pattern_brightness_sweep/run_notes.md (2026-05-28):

# NightKite Pattern/Brightness Sweep

Preparation timestamp: 2026-05-28_061232

## Firmware-Derived Test Matrix

Brightness levels: 95, 127, 159, 191, 223, 255

Patterns:
- 1 rainbow
- 2 full_color
- 3 motion_brightness
- 4 runner_fixed
- 5 runner_reactive
- 6 runner_dual
- 7 heartbeat
- 8 ping_pong
- 9 comet_swarm
- 10 breath_storm
- 11 jerk_wave
- 12 yaw_spinner
- 13 yaw_spinner_circle
- 14 runner_dual_inverted
- 15 palette_beat_motion
- 16 pacifica_kite
- 17 twinkle_motion
- 18 fire_jet
- 19 noise_ring
- 20 pride_yaw
- 21 confetti_jerk
- 22 center_ripple

## Device Discovery

NightKite USB serial: /dev/cu.usbmodem1101

NightKite identity:
- name: NK-FD6181
- uid: 576B81A319FD6181
- firmware: 4.0.0-alpha.1
- hardware: pico2350-rm2-ble
- BLE service UUID: 4e4b4000-6e69-6768-746b-000000000001
- BLE RX write UUID: 4e4b4000-6e69-6768-746b-000000000002
- BLE TX notify UUID: 4e4b4000-6e69-6768-746b-000000000003

PowerMeter USB serial: /dev/cu.usbserial-210

## Preparation Commands

NightKite USB NK4:
- NK4 seq=10 cmd=set play_mode=manual autoplay=0 wireless_enabled=1 sync_enabled=0 pattern=1 brightness=95
- NK4 seq=11 cmd=status
- NK4 seq=12 cmd=ble_status
- NK4 seq=13 cmd=get section=wireless

PowerMeter serial:
- ?
- i 100
- r
- h
- log erase
- log new nk_pattern_brightness_prep
- log status
- mark prep_ready

PowerMeter header:

```csv
runtime_ms,interval_ms,voltage_v,current_ma,signed_power_w,sensor_power_w,discharged_mah,charged_mah,net_mah,discharged_wh,charged_wh,net_wh
```

Preparation state:
- PowerMeter interval set to 100 ms.
- PowerMeter counters reset.
- PowerMeter marker support confirmed.
- PowerMeter offline logging active at /powerlog.csv.
- NightKite set to manual, autoplay off, wireless on, sync off, pattern 1, brightness 95.
- No NightKite save command was sent.

Note: while NightKite USB was connected, PowerMeter current was negative, consistent with charge/input direction. Battery-only positive current check is pending after manual restart.

## Measurement Result

Run started: 2026-05-28T04:17:28.352Z
Run ended: 2026-05-28T04:31:32.299Z
Elapsed seconds: 843.9
Segments measured: 132 of 132
Completed: true
Abort reason: none
Latest PowerMeter voltage: 4.0200 V
Latest PowerMeter current: 78.750 mA

Generated files:
- raw_powerlog.csv
- segments.csv
- summary_per_segment.csv
- summary_pivot.csv
- run_notes.md

Post-run PowerMeter cleanup:
- Sent `mark host_summary_done`.
- Sent `log stop sweep_done`.
- PowerMeter reported `LOG active=0 full=1 file=/powerlog.csv size_bytes=491205 free_bytes=491520`.
- The host-side `raw_powerlog.csv` is complete; the ESP offline flash log filled after the sweep and was stopped.

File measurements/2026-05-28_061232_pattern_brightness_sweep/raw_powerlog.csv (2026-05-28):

runtime_ms | interval_ms | voltage_v | current_ma | signed_power_w | sensor_power_w | discharged_mah | charged_mah | net_mah | discharged_wh | charged_wh | net_wh
1361483 | 100 | 4.0338 | 181.250 | 0.7311 | 0.7300 | 12.215484 | 0.790141 | 11.425343 | 0.049597 | 0.003313 | 0.046284
361583 | 100 | 4.0338 | 180.000 | 0.7261 | 0.7300 | 12.220484 | 0.790141 | 11.430343 | 0.049618 | 0.003313 | 0.046304
361683 | 100 | 4.0338 | 178.750 | 0.7210 | 0.7300 | 12.225450 | 0.790141 | 11.435309 | 0.049638 | 0.003313 | 0.046324
361783 | 100 | 4.0338 | 180.000 | 0.7261 | 0.7300 | 12.230450 | 0.790141 | 11.440309 | 0.049658 | 0.003313 | 0.046344
361883 | 100 | 4.0338 | 178.750 | 0.7210 | 0.7200 | 12.235415 | 0.790141 | 11.445274 | 0.049678 | 0.003313 | 0.046364
361983 | 100 | 4.0338 | 178.750 | 0.7210 | 0.7300 | 12.240380 | 0.790141 | 11.450239 | 0.049698 | 0.003313 | 0.046384
362083 | 100 | 4.0338 | 181.250 | 0.7311 | 0.7300 | 12.245415 | 0.790141 | 11.455274 | 0.049718 | 0.003313 | 0.046405
362183 | 100 | 4.0338 | 178.750 | 0.7210 | 0.7200 | 12.250380 | 0.790141 | 11.460239 | 0.049738 | 0.003313 | 0.046425
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

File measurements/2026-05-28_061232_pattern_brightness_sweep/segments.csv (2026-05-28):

segment_id | pattern_id | pattern_name | brightness | start_host_iso | end_host_iso | start_runtime_ms | end_runtime_ms | start_line_index | end_line_index | status
seg_001_p01_b095 | 1 | rainbow | 95 | 2026-05-28T04:17:31.739Z | 2026-05-28T04:17:36.989Z | 366860 | 372147 | 53 | 104 | ok
seg_002_p01_b127 | 1 | rainbow | 127 | 2026-05-28T04:17:38.130Z | 2026-05-28T04:17:43.377Z | 373306 | 378492 | 116 | 166 | ok
seg_003_p01_b159 | 1 | rainbow | 159 | 2026-05-28T04:17:44.522Z | 2026-05-28T04:17:49.769Z | 379626 | 384955 | 178 | 230 | ok
seg_004_p01_b191 | 1 | rainbow | 191 | 2026-05-28T04:17:50.896Z | 2026-05-28T04:17:56.144Z | 386060 | 391273 | 241 | 292 | ok
seg_005_p01_b223 | 1 | rainbow | 223 | 2026-05-28T04:17:57.273Z | 2026-05-28T04:18:02.523Z | 392461 | 397676 | 304 | 354 | ok
seg_006_p01_b255 | 1 | rainbow | 255 | 2026-05-28T04:18:03.660Z | 2026-05-28T04:18:08.899Z | 398832 | 404002 | 366 | 416 | ok
seg_007_p02_b095 | 2 | full_color | 95 | 2026-05-28T04:18:10.023Z | 2026-05-28T04:18:15.279Z | 405126 | 410463 | 428 | 480 | ok
seg_008_p02_b127 | 2 | full_color | 127 | 2026-05-28T04:18:16.405Z | 2026-05-28T04:18:21.652Z | 411591 | 416814 | 491 | 542 | ok
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

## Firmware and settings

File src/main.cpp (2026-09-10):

/*
  NightKite multi-strip controller

  Drives two WS2811 LED strips from one logical LED buffer and uses an MPU6050
  DMP packet stream for motion-reactive effects. The motion pipeline reads
  yaw/pitch/roll for orientation-reactive color and gravity-free world-frame
  acceleration for movement intensity, bursts, and pattern speed.

  Runtime configuration is available through the USB serial CLI and persisted
  to EEPROM. Board-specific pins are supplied through PlatformIO build flags
  for the supported Pico-class targets.

  Hardware overview:
  - MPU6050 on I2C with its INT pin connected to PIN_MPU_INTERRUPT.
  - Two WS2811 data outputs configured by PIN_LED_STRIP_1 and PIN_LED_STRIP_2.
  - Multi-function button, battery ADC input, and USB power sense input.
*/

// ============================================================================
//  INCLUDES
// ============================================================================

#include <Arduino.h> //Arduino.h
#include "MPU6050_6Axis_MotionApps612.h" // MPU6050 DMP library
#include <FastLED.h> // FastLED
#include "SimpleFSM.h" // State Machine
#include <SimpleCLI.h> // Serial command-line interface
#include "avdweb_Switch.h" // Button library
#include <Smoothed.h> // Smoothing library
#include <EEPROM.h> //EEPROM Library
#include <math.h> // Math library
#include <string.h>
#include "app/AudioPatternMath.h"
#include "app/Battery.h"
#include "app/ConfigMigration.h"
#include "app/OrientationColor.h"
#include "app/PatternClock.h"
#include "app/SyncEngine.h"
#include "app/SyncMath.h"
#include "protocol/CommandInput.h"
#include "protocol/NkSetTransaction.h"
#include "protocol/NkProtocol.h"
#include "wireless/Rm2Ble.h"
#include "wireless/SyncBeaconRadio.h"

// ============================================================================
//  MOTION DATA
// ============================================================================

// The LED patterns use yaw/pitch/roll for orientation-reactive color and
// gravity-free world acceleration for motion intensity.

// ============================================================================
//  HARDWARE & LED CONFIG
// ============================================================================

#ifndef PIN_MPU_INTERRUPT
#define PIN_MPU_INTERRUPT 3
#endif
#ifndef PIN_LED_STRIP_1
#define PIN_LED_STRIP_1 12
#endif
#ifndef PIN_LED_STRIP_2
#define PIN_LED_STRIP_2 13
#endif
#ifndef PIN_BUTTON_MULTI
#define PIN_BUTTON_MULTI 23
#endif
#ifndef PIN_BATTERY_ADC
#define PIN_BATTERY_ADC 29
#endif
#ifndef PIN_USB_SENSE
#define PIN_USB_SENSE 24
#endif
#ifndef PIN_RM2_WL_ON
#define PIN_RM2_WL_ON 17
#endif
#ifndef PIN_RM2_BL_ON
#define PIN_RM2_BL_ON PIN_RM2_WL_ON
#endif
#ifndef PIN_RM2_WL_CS
#define PIN_RM2_WL_CS 18
#endif
#ifndef PIN_RM2_WL_CLK
#define PIN_RM2_WL_CLK 19
#endif
#ifndef PIN_RM2_WL_DATA
#define PIN_RM2_WL_DATA 20
#endif
#ifndef PIN_RM2_WL_WAKE
#define PIN_RM2_WL_WAKE PIN_RM2_WL_DATA
#endif
#ifndef NIGHTKITE_BLE
#define NIGHTKITE_BLE 0
#endif
#ifndef NIGHTKITE_RM2
#define NIGHTKITE_RM2 0
#endif
#ifndef NIGHTKITE_HARDWARE
#define NIGHTKITE_HARDWARE "unknown"
#endif
#ifndef NIGHTKITE_BOOT_DEBUG
#define NIGHTKITE_BOOT_DEBUG 1
#endif
#ifndef NIGHTKITE_SAFE_BOOT
#define NIGHTKITE_SAFE_BOOT 0
#endif

constexpr const char* FIRMWARE_VERSION = "4.0.0-alpha.1";
constexpr uint8_t NK4_PROTOCOL_VERSION = 4;

int const INTERRUPT_PIN = PIN_MPU_INTERRUPT; // MPU interrupt input pin

#define PinStrip1 PIN_LED_STRIP_1
#define PinStrip2 PIN_LED_STRIP_2
#define LED_TYPE WS2811
#define COLOR_ORDER GRB

#define MIN_LEDS_PER_STRIP 10
#define MAX_LEDS_PER_STRIP 35
#define DEFAULT_LEDS_PER_STRIP 25
#define MAX_TOTAL_LEDS (MAX_LEDS_PER_STRIP * 2)

constexpr unsigned long BATTERY_SAMPLE_INTERVAL_MS = 1000;
constexpr uint8_t BATTERY_SAMPLE_WINDOW = 15;

int ledsPerStrip = DEFAULT_LEDS_PER_STRIP;
int totalLeds = (DEFAULT_LEDS_PER_STRIP * 2); // total logical LEDs across both strips

#define NUM_LEDS ledsPerStrip
#define TOTAL_LEDS totalLeds
#define NUM_COMETS 4        // comet count


// Logical LED buffer used by all patterns (contiguous: strip1 then strip2).
CRGB Strip[MAX_TOTAL_LEDS];
// Physical LED buffer wired as two fixed hardware segments.
CRGB PhysicalStrip[MAX_TOTAL_LEDS];

int BRIGHTNESS = 95;
#define MIN_BRIGHTNESS 95
#define MAX_BRIGHTNESS 255
#define FRAMES_PER_SECOND 120

uint8_t gHue = 0; // rotating "base color" used by many of the patterns

// ============================================================================
//  EEPROM LAYOUT
// ============================================================================

// Memory layout in emulated EEPROM.
// On Pico-class MCUs an int is 4 bytes, so values are packed sequentially.
#define EEPROM_ADDR_PATTERN         0
#define EEPROM_ADDR_BRIGHTNESS      sizeof(int)
#define EEPROM_ADDR_STRIP_LENGTH    (sizeof(int) * 2)
#define EEPROM_ADDR_SMOOTHING_SIZE  (sizeof(int) * 3)
#define EEPROM_ADDR_ACCEL_RANGE     (sizeof(int) * 4)
#define EEPROM_ADDR_GYRO_RANGE      (sizeof(int) * 5)
#define EEPROM_ADDR_BOOT_CAL_MODE   (sizeof(int) * 6)
#define EEPROM_ADDR_X_ACCEL_OFFSET  (sizeof(int) * 7)
#define EEPROM_ADDR_Y_ACCEL_OFFSET  (sizeof(int) * 8)
#define EEPROM_ADDR_Z_ACCEL_OFFSET  (sizeof(int) * 9)
#define EEPROM_ADDR_X_GYRO_OFFSET   (sizeof(int) * 10)
#define EEPROM_ADDR_Y_GYRO_OFFSET   (sizeof(int) * 11)
#define EEPROM_ADDR_Z_GYRO_OFFSET   (sizeof(int) * 12)
#define EEPROM_ADDR_MAGIC           (sizeof(int) * 13)
#define EEPROM_ADDR_ENABLED_PATTERNS (sizeof(int) * 14)
#define EEPROM_ADDR_INVERTED_PATTERNS (sizeof(int) * 15)
#define EEPROM_ADDR_AUTOPLAY_ENABLED (sizeof(int) * 16)
#define EEPROM_ADDR_AUTOPLAY_INTERVAL_MS (sizeof(int) * 17)
#define EEPROM_ADDR_DEVICE_UID       80
#define EEPROM_ADDR_DEVICE_NAME      100
#define EEPROM_ADDR_CONFIG_VERSION   132
#define EEPROM_ADDR_PLAY_MODE        136
#define EEPROM_ADDR_BOOT_MODE        140
#define EEPROM_ADDR_SYNC_ENABLED     144
#define EEPROM_ADDR_SYNC_GROUP_ID    148
#define EEPROM_ADDR_SYNC_ROLE        152
#define EEPROM_ADDR_SYNC_MASTER_UID  156
#define EEPROM_ADDR_SYNC_LOSS_BEHAVIOR 176
#define EEPROM_ADDR_WIRELESS_ENABLED 180
#define EEPROM_ADDR_WIRELESS_PROFILE 184
#define EEPROM_ADDR_SHOW_CONTROL_ENABLED 188
const int EEPROM_MAGIC = 0x4E4B3434; // "NK44"

// Size of emulated EEPROM.
// Must cover all persisted ints plus the enabled/inverted pattern bitmasks.
#define EEPROM_SIZE 224

const size_t DEVICE_UID_LENGTH = 16;
const size_t SHORT_ID_LENGTH = 6;
const size_t DEVICE_NAME_LENGTH = 24;

const int PLAY_MODE_MANUAL = 0;
const int PLAY_MODE_AUTOPLAY = 1;
const int PLAY_MODE_SYNC = 2;
const int BOOT_MODE_LAST = 0;
const int BOOT_MODE_MANUAL = 1;
const int BOOT_MODE_AUTOPLAY = 2;
const int BOOT_MODE_SYNC = 3;
const int SYNC_ROLE_STANDALONE = 0;
const int SYNC_ROLE_MASTER = 1;
const int SYNC_ROLE_FOLLOWER = 2;
const int SYNC_LOSS_CONTINUE_LOCAL = 0;
const int SYNC_LOSS_FALLBACK_AUTOPLAY = 1;
const int SYNC_LOSS_WARNING_ONLY = 2;
const int WIRELESS_PROFILE_LONG_RANGE = 0;
const int WIRELESS_PROFILE_BALANCED = 1;
const int WIRELESS_PROFILE_FAST_SYNC = 2;
const int PATTERN_SYNC_UNKNOWN = 0;
const int PATTERN_SYNC_READY = 1;
const int PATTERN_SYNC_PARTIAL = 2;
const int PATTERN_SYNC_LOCAL_REACTIVE = 3;

// Persisted configuration values.
int currentPattern = 1;
int currentBrightness = 95;
int currentStripLength = DEFAULT_LEDS_PER_STRIP;
int currentMotionSmoothingSize = 100;
int currentAccelRange = 2;
int currentGyroRange = 2000;
int currentBootCalibrationMode = 1;
int currentXAccelOffset = -3137;
int currentYAccelOffset = -7;
int currentZAccelOffset = 3687;
int currentXGyroOffset = 111;
int currentYGyroOffset = -6;
int currentZGyroOffset = 34;
uint32_t currentEnabledPatternMask = 0;
uint32_t currentInvertedPatternMask = 0;
int currentAutoplayEnabled = 0;
int currentAutoplayIntervalMs = 20000;
int currentConfigVersion = CONFIG_VERSION_CURRENT;
char currentDeviceUid[DEVICE_UID_LENGTH + 1] = "";
char currentShortId[SHORT_ID_LENGTH + 1] = "";
char currentDeviceName[DEVICE_NAME_LENGTH + 1] = "";
int currentPlayMode = PLAY_MODE_MANUAL;
int currentBootMode = BOOT_MODE_LAST;
int currentSyncEnabled = 0;
int currentSyncGroupId = 1;
int currentSyncRole = SYNC_ROLE_STANDALONE;
char currentSyncMasterUid[DEVICE_UID_LENGTH + 1] = "";
int currentSyncLossBehavior = SYNC_LOSS_CONTINUE_LOCAL;
int currentWirelessEnabled = 0;
int currentWirelessProfile = WIRELESS_PROFILE_BALANCED;
uint8_t lastBeaconPattern = 0;
uint8_t lastBeaconBrightness = 0;
uint16_t lastBeaconSeq = 0;
uint16_t lastAppliedSeq = 0;
uint32_t lastBeaconPhaseMs = 0;
unsigned long syncApplyCount = 0;
unsigned long syncApplySkipped = 0;
const char* syncApplyReason = "none";
unsigned long syncLossCount = 0;
unsigned long lastSyncLossMs = 0;
const char* lastSyncLossAction = "none";
unsigned long patternChangeCount = 0;
unsigned long lastPatternChangeMs = 0;
unsigned long lastPatternChangeLatencyMs = 0;
uint8_t lastPatternFrom = 0;
uint8_t lastPatternTo = 0;
const char* lastPatternChangeSource = "none";

// Last values written to EEPROM.
// Used to avoid unnecessary flash writes.
int lastSavedPattern = 1;
int lastSavedBrightness = 95;
int lastSavedStripLength = DEFAULT_LEDS_PER_STRIP;
int lastSavedMotionSmoothingSize = 100;
int lastSavedAccelRange = 2;
int lastSavedGyroRange = 2000;
int lastSavedBootCalibrationMode = 1;
int lastSavedXAccelOffset = -3137;
int lastSavedYAccelOffset = -7;
int lastSavedZAccelOffset = 3687;
int lastSavedXGyroOffset = 111;
int lastSavedYGyroOffset = -6;
int lastSavedZGyroOffset = 34;
uint32_t lastSavedEnabledPatternMask = 0;
uint32_t lastSavedInvertedPatternMask = 0;
int lastSavedAutoplayEnabled = 0;
int lastSavedAutoplayIntervalMs = 20000;
int lastSavedConfigVersion = CONFIG_VERSION_CURRENT;
char lastSavedDeviceUid[DEVICE_UID_LENGTH + 1] = "";
char lastSavedDeviceName[DEVICE_NAME_LENGTH + 1] = "";
int lastSavedPlayMode = PLAY_MODE_MANUAL;
int lastSavedBootMode = BOOT_MODE_LAST;
int lastSavedSyncEnabled = 0;
int lastSavedSyncGroupId = 1;
int lastSavedSyncRole = SYNC_ROLE_STANDALONE;
char lastSavedSyncMasterUid[DEVICE_UID_LENGTH + 1] = "";
int lastSavedSyncLossBehavior = SYNC_LOSS_CONTINUE_LOCAL;
int lastSavedWirelessEnabled = 0;
int lastSavedWirelessProfile = WIRELESS_PROFILE_BALANCED;

const int DEFAULT_MOTION_SMOOTHING_SIZE = 100;
const int MIN_MOTION_SMOOTHING_SIZE = 1;
const int MAX_MOTION_SMOOTHING_SIZE = 512;

const int DEFAULT_ACCEL_RANGE = 2;
const int DEFAULT_GYRO_RANGE = 2000;
const int DEFAULT_BOOT_CALIBRATION_MODE = 1;
const int DEFAULT_AUTOPLAY_ENABLED = 0;
const int DEFAULT_AUTOPLAY_INTERVAL_MS = 20000;
const int DEFAULT_PLAY_MODE = PLAY_MODE_MANUAL;
const int DEFAULT_BOOT_MODE = BOOT_MODE_LAST;
const int DEFAULT_SYNC_ENABLED = 0;
const int DEFAULT_SYNC_GROUP_ID = 1;
const int DEFAULT_SYNC_ROLE = SYNC_ROLE_STANDALONE;
const int DEFAULT_SYNC_LOSS_BEHAVIOR = SYNC_LOSS_CONTINUE_LOCAL;
const int DEFAULT_WIRELESS_ENABLED = 0;
const int DEFAULT_WIRELESS_PROFILE = WIRELESS_PROFILE_BALANCED;
const int MIN_AUTOPLAY_INTERVAL_MS = 1000;
const int MAX_AUTOPLAY_INTERVAL_MS = 300000;

const int BOOT_CALIBRATION_MODE_OFF = 0;
const int BOOT_CALIBRATION_MODE_QUICK = 1;

const int DEFAULT_X_ACCEL_OFFSET = -3137;
const int DEFAULT_Y_ACCEL_OFFSET = -7;
const int DEFAULT_Z_ACCEL_OFFSET = 3687;
const int DEFAULT_X_GYRO_OFFSET = 111;
const int DEFAULT_Y_GYRO_OFFSET = -6;
const int DEFAULT_Z_GYRO_OFFSET = 34;
const uint8_t FIRST_PATTERN_ID = NK_PATTERN_MIN_ID;
const uint8_t LAST_PATTERN_ID = NK_PATTERN_MAX_ID;
const uint8_t PATTERN_COUNT = LAST_PATTERN_ID - FIRST_PATTERN_ID + 1;
const uint32_t ALL_ENABLED_PATTERN_MASK = (1ul << PATTERN_COUNT) - 1ul;
const uint32_t ALL_INVERTED_PATTERN_MASK = (1ul << PATTERN_COUNT) - 1ul;
static_assert(
    AUDIO_SYNC_PATTERN_MASK == (ALL_ENABLED_PATTERN_MASK & ~((1ul << 22) - 1ul)),
    "Config migration mask must cover patterns 23 through 27");

int activeMotionSmoothingSize = DEFAULT_MOTION_SMOOTHING_SIZE;

// supported brightness levels for button + CLI
const int BRIGHTNESS_LEVELS[] = {95, 127, 159, 191, 223, 255};
const size_t BRIGHTNESS_LEVEL_COUNT = sizeof(BRIGHTNESS_LEVELS) / sizeof(BRIGHTNESS_LEVELS[0]);

// for timekeeping
unsigned long lastUpdateTime = 0;
const unsigned long UPDATE_INTERVAL = 5 * 60 * 1000; // 5 minutes in milliseconds (5 * 60 * 1000)
const unsigned long BATTERY_VIEW_TIMEOUT_MS = 5000;
unsigned long batteryViewLastInteractionMs = 0;

// ====================================================================
//  USB CLI STATE
// ====================================================================

SimpleCLI cli;
String cliInputBuffer;
bool cliInputOverflow = false;
bool cliPromptShown = false;
unsigned long cliLastInputMs = 0;
const unsigned long CLI_AUTOPARSE_TIMEOUT_MS = 200;
bool cliSessionBannerPending = false;
unsigned long cliSessionBecameActiveMs = 0;
const unsigned long CLI_CONNECT_BANNER_DELAY_MS = 150;
enum UsbProtocolMode
{
  USB_PROTOCOL_HUMAN = 0,
  USB_PROTOCOL_MACHINE = 1
};
UsbProtocolMode usbProtocolMode = USB_PROTOCOL_HUMAN;
bool configValid = false;
bool configRepaired = false;
bool eepromReady = false;
bool safeBootActive = (NIGHTKITE_SAFE_BOOT != 0);
bool imuReady = false;
const char* bootStage = "reset";
bool bootLoopAnnounced = false;

// ============================================================================
//  MPU6050 & MOTION STATE
// ============================================================================
/* MPU6050 default I2C address is 0x68*/
MPU6050 mpu;

/*---MPU6050 Control/Status Variables---*/
bool DMPReady = false;  // Set true if DMP init was successful
uint8_t MPUIntStatus;   // Holds actual interrupt status byte from MPU
uint8_t devStatus;      // Return status after each device operation (0 = success, !0 = error)
uint16_t packetSize;    // Expected DMP packet size (default is 42 bytes)
uint8_t FIFOBuffer[64]; // FIFO storage buffer

/*---Orientation/Motion Variables---*/
Quaternion q;        // [w, x, y, z]         Quaternion container
VectorInt16 aa;      // [x, y, z]            Accel sensor measurements
VectorInt16 gy;      // [x, y, z]            Gyro sensor measurements
VectorInt16 aaReal;  // [x, y, z]            Gravity-free accel sensor measurements
VectorInt16 aaWorld; // [x, y, z]            World-frame accel sensor measurements
VectorFloat gravity; // [x, y, z]            Gravity vector
float ypr[3];        // [yaw, pitch, roll]   Yaw/Pitch/Roll container and gravity vector

volatile bool MPUInterrupt = false; // Indicates whether MPU6050 interrupt pin has gone high
/*------Interrupt detection routine------*/
void DMPDataReady(){
  MPUInterrupt = true;
}

// ============================================================================
//  BUTTON, BATTERY, TIMING
// ============================================================================

// Button handling.
const byte multiresponseButtonpin = PIN_BUTTON_MULTI;
Switch multiresponseButton = Switch(multiresponseButtonpin, INPUT);

// Battery, charging, and serial-session state.
int UsbConnected = 0;
int UsbPowerRaw = 0;
bool SerialSessionActive = false;
int RawVoltage = 0;
float Voltage = 0;
int BatteryPercent = 0;
BatteryState currentBatteryState = BATTERY_STATE_NORMAL;
BatteryStateTracker batteryStateTracker;
float batteryVoltageSamples[BATTERY_SAMPLE_WINDOW] = {0};
uint8_t batteryVoltageSampleCount = 0;
uint8_t batteryVoltageSampleIndex = 0;
float batteryVoltageSampleSum = 0.0f;
unsigned long lastBatterySampleMs = 0;
bool lowPowerCutoffActive = false;
bool lowPowerCutoffSaved = false;
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
void loop()
{
  if (!bootLoopAnnounced)
  {
    bootMark("loop");
    bootLoopAnnounced = true;
  }

  const uint32_t loopStartUs = micros();
  /* Read a packet from FIFO */
  if (DMPReady && mpu.dmpGetCurrentFIFOPacket(FIFOBuffer))
  { // Get the Latest packet
    // Orientation for hue/rotation-reactive patterns.
    mpu.dmpGetQuaternion(&q, FIFOBuffer);
    mpu.dmpGetGravity(&gravity, &q);
    mpu.dmpGetYawPitchRoll(ypr, &q, &gravity);
    // Gravity-free world-frame acceleration for motion-reactive patterns.
    mpu.dmpGetAccel(&aa, FIFOBuffer);
    mpu.dmpGetLinearAccel(&aaReal, &aa, &gravity);
    mpu.dmpGetLinearAccelInWorld(&aaWorld, &aaReal, &q);

    /* Blink LED to indicate activity */
    blinkState = !blinkState;
    digitalWrite(LED_BUILTIN, blinkState);
  }

  // Periodically persist changed configuration values.
    unsigned long currentTime = millis();
    if (currentTime - lastUpdateTime >= UPDATE_INTERVAL) {
        // Set timestamp for the next check.
        lastUpdateTime = currentTime;

        if (usbProtocolMode == USB_PROTOCOL_HUMAN)
        {
          Serial.println("5 minute interval reached. Checking values for changes...");
        }

        const bool syncTimingActive = (syncEngine.state == SyncEngine::ARMED || syncEngine.state == SyncEngine::RUNNING ||
            showReceiveEnabled || showState.active() || syncBeaconShowStatus().queueDepth > 0);
        // Save only when something actually changed and no local sync timing is active.
        if (hasUnsavedConfigChanges() && !syncTimingActive) {
            // At least one value changed.
            if (usbProtocolMode == USB_PROTOCOL_HUMAN)
            {
              Serial.println("Values have changed. Saving new values to EEPROM...");
            }
            saveConfigToEEPROM(usbProtocolMode == USB_PROTOCOL_HUMAN);
        } else if (syncTimingActive && hasUnsavedConfigChanges()) {
            if (usbProtocolMode == USB_PROTOCOL_HUMAN)
            {
              Serial.println("Sync timing active. Deferring EEPROM update.");
            }
        } else {
            // No change.
            if (usbProtocolMode == USB_PROTOCOL_HUMAN)
            {
              Serial.println("Values are unchanged. No EEPROM update needed.");
            }
        }
    }

  // Periodic shared hue update used by several patterns.
  EVERY_N_MILLISECONDS(20) { gHue++; } // Slowly cycle the shared base hue.

  // USB power state for charging behavior and CLI session detection.
  UsbPowerRaw = digitalRead(PIN_USB_SENSE);
  const bool previousSerialSessionActive = SerialSessionActive;
  SerialSessionActive = ((bool)Serial) && Serial.dtr();
  if (SerialSessionActive && !previousSerialSessionActive)
  {
    cliSessionBecameActiveMs = millis();
    cliSessionBannerPending = true;
    cliPromptShown = false;
    resetCliInput();
  }
  // Disable the charging view while a serial session is active.
  UsbConnected = (UsbPowerRaw == 1 && !SerialSessionActive) ? 1 : 0;

  updateBatteryMeasurement(false);
  handleBatteryCutoff();
  if (lowPowerCutoffActive)
  {
    delay(50);
    return;
  }

  multiresponseButton.poll();

  if (multiresponseButton.longPress())
  {
    fsm.trigger(longpress);
  }

  if (multiresponseButton.doubleClick())
  {
    if (batteryViewActive)
    {
      cyclePlayMode();
      batteryViewLastInteractionMs = millis();
      if (usbProtocolMode == USB_PROTOCOL_MACHINE)
      {
        String fields = "play_mode=";
        fields += playModeToString(currentPlayMode);
        fields += " autoplay=";
        fields += currentAutoplayEnabled;
        emitNk4Event("play_mode_changed", fields);
      }
      else
      {
        Serial.print("INFO play_mode=");
        Serial.print(playModeToString(currentPlayMode));
        Serial.print(" autoplay=");
        Serial.println(autoplayEnabledToString());
      }
    }
    else if (!UsbConnected)
    {
      switchToPattern(getNextEnabledPattern((uint8_t)currentPattern), false, "button");
      announcePatternChange("button");
    }
  }

  // USB-only power enters the charging state unless a serial session is active.
  if (UsbConnected == 1)
  {
    fsm.trigger(usbpower);
  }

  handleCLI();
  rm2BleTick();
  patternClock.tick();
  syncEngine.tick();
  tickSyncBeaconRadio();
  applySyncStartIfDue();
  tickShowControl();

  if (multiresponseButton.singleClick() && batteryViewActive)
  {
    BRIGHTNESS += 32; // Brightness range is 95..255 in steps of 32.
    if (BRIGHTNESS > MAX_BRIGHTNESS)
    {
      BRIGHTNESS = MIN_BRIGHTNESS; // Wrap around to the minimum brightness.
    }
    currentBrightness = BRIGHTNESS;
    applyEffectiveBrightness();
    batteryViewLastInteractionMs = millis();
  }

  const bool autoplayPaused = batteryViewActive || UsbConnected;
  if (shouldRunAutoplayTick())
  {
    if (autoplayPaused)
    {
      autoplayWasPaused = true;
    }
    else
    {
      if (autoplayWasPaused)
      {
        resetAutoplayTimer();
      }
      if (millis() - autoplayLastSwitchMs >= (unsigned long)currentAutoplayIntervalMs)
      {
        switchToPattern(getNextEnabledPattern((uint8_t)currentPattern), false, "autoplay");
        announcePatternChange("autoplay");
      }
    }
  }
  else
  {
    autoplayWasPaused = false;
  }

  // Execute events before rendering their first visible frame.
  fsm.run(0);
  if (showState.active() && !batteryViewActive && !UsbConnected)
    FastLED.setBrightness(showState.selectedBrightness(BRIGHTNESS));

  // Copy the logical LEDs into the fixed physical strip layout and show them.
  clearInactiveLeds();
  applyBatteryBrightnessLimit();
  syncLogicalToPhysicalLeds();
  FastLED.show();

  lastWorkDurationUs = micros() - loopStartUs;
  totalWorkDurationUs += lastWorkDurationUs;
  if (lastWorkDurationUs > maxWorkDurationUs)
  {
    maxWorkDurationUs = lastWorkDurationUs;
  }

  // Keep the framerate bounded by the configured frame budget after all
  // per-frame work has completed.
  const uint32_t frameBudgetUs = 1000000UL / FRAMES_PER_SECOND;
  if (lastWorkDurationUs < frameBudgetUs)
  {
    delayMicroseconds(frameBudgetUs - lastWorkDurationUs);
  }

  lastLoopDurationUs = micros() - loopStartUs;
  totalLoopDurationUs += lastLoopDurationUs;
  if (lastLoopDurationUs > maxLoopDurationUs)
  {
    maxLoopDurationUs = lastLoopDurationUs;
  }
  loopTimingSamples++;
}

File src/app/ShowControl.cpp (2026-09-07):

#include "ShowControl.h"
#include <string.h>

namespace
{
int32_t sequenceDelta(uint16_t a, uint16_t b)
{
  const uint16_t delta = a - b;
  return delta <= INT16_MAX ? delta : (int32_t)delta - 65536;
}
}

void ShowScheduler::reset()
{
  count = 0;
  clockReady = false;
  recentCount = nextRecent = 0;
}

void ShowScheduler::sampleClock(uint32_t senderMs, uint32_t receiveMs, bool clockPacket)
{
  // Repeated controller advertisements carry stale timestamps: never re-sample them.
  if (clockReady && senderMs == lastSenderMs) return;
  // A replacement gateway may restart its clock. Fresh CLOCK warmup can rebase
  // after 2 s without forward samples; queued deadlines remain frozen.
  const bool restart = clockPacket && clockReady && receiveMs - lastClockRxMs >= 2000;
  if (clockReady && showTimeDelta(senderMs, lastSenderMs) <= 0 && !restart) return;
  const uint32_t sample = receiveMs - senderMs - NK_SHOW_RX_COMPENSATION_MS;
  // ponytail: minimum receive latency in a 2 s window; hardware timestamping if measured jitter requires it.
  if (!clockReady || restart || receiveMs - sampleWindowMs >= 2000)
  {
    offsetMs = sample;
    sampleWindowMs = receiveMs;
  }
  else if (showTimeDelta(sample, offsetMs) < 0) offsetMs = sample;
  clockReady = true;
  lastSenderMs = senderMs;
  lastClockRxMs = receiveMs;
  ++status.clockSamples;
}

bool ShowScheduler::seen(uint16_t id) const
{
  // Equality only: IDs are not a monotonic sender identity. Queued events stay
  // protected even if more than 64 other events pass through the recent cache.
  for (uint8_t i = 0; i < count; ++i) if (queue[i].packet.eventId == id) return true;
  for (uint8_t i = 0; i < recentCount; ++i) if (recentIds[i] == id) return true;
  return false;
}

void ShowScheduler::remember(uint16_t id)
{
  recentIds[nextRecent] = id;
  nextRecent = (nextRecent + 1) % NK_SHOW_DEDUPE_CAPACITY;
  if (recentCount < NK_SHOW_DEDUPE_CAPACITY) ++recentCount;
}

bool ShowScheduler::receive(const ShowPacket& packet, uint32_t receiveMs, uint32_t nowMs)
{
  if (validateShowPacket(packet) != ShowDecodeResult::OK) return false;
  sampleClock(packet.senderMs, receiveMs, packet.command == ShowCommand::CLOCK);
  if (packet.command == ShowCommand::CLOCK) return true;
  if (seen(packet.eventId))
  {
    ++status.duplicates;
    return false;
  }
  const uint32_t due = showExecuteTime(packet) + offsetMs;
  const int32_t ahead = showTimeDelta(due, nowMs);
  if (ahead < -NK_SHOW_MAX_LATE_MS)
  {
    remember(packet.eventId);
    ++status.late;
    ++status.droppedLate;
    return false;
  }
  if (ahead > NK_SHOW_MAX_AHEAD_MS)
  {
    ++status.stale; // Timing rejection after clock mapping; not an ID-age rule.
    return false;
  }
  if (count == NK_SHOW_QUEUE_CAPACITY)
  {
    ++status.full; // No eviction, and no dedupe mark: a later retry may fit.
    return false;
  }
  ShowScheduledEvent event;
  event.packet = packet;
  event.dueMs = due;
  uint8_t i = count;
  while (i > 0 && (showTimeDelta(due, queue[i - 1].dueMs) < 0 ||
      (due == queue[i - 1].dueMs && sequenceDelta(packet.eventId, queue[i - 1].packet.eventId) < 0)))
  {
    queue[i] = queue[i - 1];
    --i;
  }
  queue[i] = event;
  ++count;
  remember(packet.eventId);
  ++status.accepted;
  return true;
}

bool ShowScheduler::popDue(uint32_t nowMs, ShowScheduledEvent& event)
{
  while (count && showTimeDelta(nowMs, queue[0].dueMs) >= 0)
  {
    event = queue[0];
    for (uint8_t i = 1; i < count; ++i) queue[i - 1] = queue[i];
    --count;
    status.lastDueMs = event.dueMs;
    status.lastLatenessMs = nowMs - event.dueMs;
    if (status.lastLatenessMs) ++status.late;
    if (status.lastLatenessMs > (uint32_t)NK_SHOW_MAX_LATE_MS)
    {
      ++status.droppedLate;
      continue;
    }
    return true;
  }
  return false;
}

bool ShowState::pendingComplete() const
{
  const uint32_t expected = pendingSegments == 32 ? UINT32_MAX : (uint32_t(1) << pendingSegments) - 1;
  return pendingValid && receivedSegments == expected;
}

void ShowState::release()
{
  output = ShowOutput::UNDERLYING;
  brightness = 0;
  pendingValid = false;
  receivedSegments = 0;
  ++revision;
}

bool ShowState::apply(const ShowPacket& p, uint32_t dueMs, uint8_t localBrightness, uint8_t ledCount)
{
  lastEvent = p.eventId;
  lastCommand = (uint8_t)p.command;
  if (validateShowPacket(p) != ShowDecodeResult::OK || ledCount == 0 || ledCount > NK_SHOW_MAX_LEDS)
  {
    ++rejected;
    return false;
  }
  const auto reject = [this]() { ++rejected; return false; };
  switch (p.command)
  {
    case ShowCommand::SET_PATTERN:
      output = ShowOutput::PATTERN;
      pattern = p.params[0];
      patternStartMs = dueMs;
      ++revision;
      break;
    case ShowCommand::SET_BRIGHTNESS: brightness = p.params[0]; break;
    case ShowCommand::SET_SOLID:
      output = ShowOutput::SOLID;
      solid.r = p.params[0]; solid.g = p.params[1]; solid.b = p.params[2];
      if (p.params[3]) brightness = p.params[3];
      break;
    case ShowCommand::BLACKOUT: output = ShowOutput::BLACKOUT; break;
    case ShowCommand::RELEASE: release(); break;
    case ShowCommand::CLEAR_PENDING:
      pendingValid = true;
      pendingId = p.params[0]; pendingSegments = p.params[1]; pendingLedCount = ledCount;
      receivedSegments = 0;
      for (auto& rgb : pending) rgb = ShowRgb{};
      break;
    case ShowCommand::SET_SEGMENT:
      if (!pendingValid || pendingId != p.params[0] || pendingLedCount != ledCount ||
          p.params[1] >= pendingSegments || (uint16_t)p.params[2] + p.params[3] > ledCount ||
          (receivedSegments & (uint32_t(1) << p.params[1]))) return reject();
      for (uint8_t i = p.params[2]; i < p.params[2] + p.params[3]; ++i)
      {
        pending[i].r = p.params[4]; pending[i].g = p.params[5]; pending[i].b = p.params[6];
      }
      receivedSegments |= uint32_t(1) << p.params[1];
      break;
    case ShowCommand::APPLY_PENDING:
      if (!pendingComplete() || p.params[0] != pendingId || pendingLedCount != ledCount) return reject();
      memcpy(front, pending, sizeof(front));
      output = ShowOutput::BUFFER;
      break;
    case ShowCommand::CLOCK: return true;
  }
  if (controlsOutput() && brightness == 0) brightness = localBrightness;
  ++executed;
  return true;
}

ShowRgb ShowState::pixel(uint8_t index) const
{
  if (output == ShowOutput::SOLID) return solid;
  if (output == ShowOutput::BUFFER && index < NK_SHOW_MAX_LEDS) return front[index];
  return ShowRgb{};
}

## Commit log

2025-04-21 add case
    [nightkite-multi.3mf, nightkite-multi.step]
2025-07-24 making pattern storage work with battery and charge mode
2025-08-01 addes new led pattern and changed led strip configuration
2025-08-26 new patterns and some typo fixes
    [main.cpp]
2025-08-28 typo fixes in state maschine
    [main.cpp]
2025-10-12 added new pattern. running6 inverted as running13
    [main.cpp]
2025-10-12 re enabled usb charging (disabled debug mode)
2025-11-06 typo fix. running 13 state name
    [main.cpp]
2026-03-09 added support for new board (pimoroni pico lipo 2)
2026-03-09 restrict brightness control to battery view and added a brightness indicator.
2026-03-09 disable charging display while serial active
2026-03-09 implemented different lenghts of led strips
2026-03-10 integration of precise imu calibration into cli
2026-03-14 new cli command to enable and disable patterns, redesigned the pattern system.
    [main.cpp]
2026-03-24 Fix frame pacing to honor frame budget
    [main.cpp]
2026-03-25 Adjust battery display voltage thresholds
2026-03-25 Add circular yaw spinner pattern
2026-04-28 Move frame limiter to end of loop
2026-04-28 Polish battery and setup comments
2026-04-28 Add timing reset CLI command
    [main.cpp]
2026-05-14 Improve USB reboot handling
    [main.cpp]
2026-05-16 Update RM2 wiring pins for outer-pad breakout
2026-05-16 Pin PlatformIO library dependencies
2026-05-16 Stabilize BLE NK4 notify pacing
    [Rm2Ble.cpp]
2026-05-16 Fix BLE NK4 notify queue progression
    [Rm2Ble.cpp]
2026-05-17 Fix sync beacon advertising ownership
    [Rm2Ble.cpp]
2026-05-17 Use PatternClock across LED patterns
2026-05-27 Improve battery state handling
2026-05-28 Add pattern brightness power sweep measurements
    [raw_powerlog.csv, segments.csv, summary_per_segment.csv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]
2026-06-27 Stabilize audio sync pattern handling
    [main.cpp]
2026-07-23 Fix long BLE NK4 responses
    [Rm2Ble.cpp]
2026-07-23 Fix persistent config recovery
    [main.cpp]
2026-07-23 Fix USB command framing and numeric parsing
    [main.cpp]
2026-07-23 Fix BLE advertising and ATT write validation
    [Rm2Ble.cpp]
2026-07-23 Decouple battery protection from display hysteresis
2026-07-23 Stabilize orientation colors between IMU samples
    [main.cpp]
2026-07-24 Add NK4 calibration compatibility
